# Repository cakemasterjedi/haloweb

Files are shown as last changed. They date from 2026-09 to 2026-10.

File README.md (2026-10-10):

# Digital BMW emblem (ESP32-S3 2.8" round display)

Board: [Waveshare ESP32-S3-LCD-2.8C](https://www.waveshare.com/wiki/ESP32-S3-LCD-2.8C).
The display is driven the same way as Waveshare's own demo: same ST7701 start-up
commands over hardware SPI, and ESP-IDF's RGB panel driver with the demo's pins,
timings and bounce buffers (Arduino core 3.x via pioarduino).

Firmware that turns the ESP32-S3 2.8" 480×480 round display board into a
digital roundel for the car. You control it from your phone's browser, so
there's no app to install.

## Install it (no coding needed)

Open the **[web installer](https://cakemasterjedi.github.io/haloweb/)** in Chrome or Edge on a
computer, plug the board in with a USB-C data cable and click **Install**. It always has the
newest build, plus the update file for installing updates from your phone later.

The installer is built and published automatically by
[`.github/workflows/web-installer.yml`](.github/workflows/web-installer.yml) on every push to
`main` that changes the firmware.

## What it can show

| Mode | What it looks like | Speed slider |
|---|---|---|
| **Roundel** | The classic badge: thin silver rims, glossy black ring with bold upright lettering, blue and white quarters. Colours and lettering are editable; presets Classic, Blackout, Motorsport, Carbon, Gold | – |
| **Spin** | Roundel with the quarters rotating | spin speed / direction |
| **Stripes** | M tri-colour stripes on carbon-fibre twill | 0 = static, otherwise scrolls |
| **Picture** | Photos, GIFs or videos from your phone (10 slots). Fill / Fit / Fit circle, zoom (pinch), drag, rotate | – |
| **Text** | Your own text, `\|` starts a new line (e.g. `M\|POWER`) | – |
| **M 50** | The "50 Years of BMW M" badge (the 1973 BMW Motorsport emblem): a small classic roundel on white enamel with light blue, dark blue and red half circles around it | – |
| **M 50 Spin** | M 50 with the quarters rotating | spin speed / direction |

All modes also have **brightness** and **rotation** (to level the emblem if it's
mounted at an angle). Settings are saved on the board.

- **Colours:** tapping any colour opens a colour wheel (works the same in
  Firefox and Chrome) with brightness and saturation sliders, hex and RGB
  entry, BMW paint colours and your recent colours. The emblem follows as you
  pick; Cancel puts the old colour back.

- **Auto-cycle** (Emblem tab): rotates through the designs you pick (modes and
  picture slots) every 5 s – 10 min. An animation finishes its loop before the
  next design comes on.
- **Smooth transitions:** designs crossfade into each other (Settings).
- **Animation speed:** 25–300 % for uploaded animations (Emblem tab, shown when
  an animation is selected).
- **Special dates** (Emblem tab): a design for certain days every year, e.g.
  1–26 Dec → your Christmas animation (up to 8 dates, presets for common
  holidays). On those days it replaces the normal design and auto-cycle.
- **Start-up** (Settings): the built-in animation (the ring sweeps in, the
  quarters spin into place, a glint crosses the badge), any picture or
  animation slot, or off. Then your selected design takes over.

## Power (the Power tab)

- **Normal mode:** optionally turns itself off after 5 min – 4 h, counted from
  power-on or your last change on the phone.
- **Car show mode:** stays on (for 1–24 h, or until the battery is low) with its
  own brightness.
- **Battery protection:** live voltage readout; turns off if the voltage stays
  below your cutoff for 30 s (so cranking dips don't trigger it). After a
  low-voltage shutdown it wakes every 10 minutes and comes back on once the
  battery is above the cutoff + 0.3 V.
- **Voltage source:**
  - *Board LiPo* – a battery on the board's battery connector (GPIO4).
  - *Car battery* – an **INA219** module on the board's I2C connector
    (SDA 15, SCL 7, 3.3 V, GND; VIN+ to the car battery +, VIN- can be left
    unconnected, and the module's GND to the car's ground). Every analog pin that
    works alongside Wi-Fi is taken by the display, so a 12 V battery can't be read
    directly.
  - Calibrate against a multimeter reading from the page.
- **Night dimming:** its own brightness between two times (default 19:00 –
  07:00), fading over. The board's clock chip keeps the time while it has
  power; it's set whenever you open the page, and from the internet when it's
  on your hotspot.
- **"Off" is deep sleep:** screen, backlight and Wi-Fi off. Wake it with the
  **BOOT** button or by cutting and restoring power. The board still draws a
  little current asleep (regulator, USB chip, LEDs), so for zero drain use an
  ignition-switched supply.

> **Auto-off and always-on fuses:** if the emblem runs from an always-on fuse, leave
> **Power → Turn off after** on **Never** unless you've fitted a kill switch. Once auto-off turns it
> off, it stays off until the BOOT button on the board is pressed (or a kill switch cuts and restores
> its power). Battery protection is
> separate: after a low-voltage shutdown it wakes by itself.

## G30 trunk emblem build

Want it in place of the trunk roundel on a G30 5 Series? The [`hardware`](hardware) folder has a slim
88 mm 3D-printed housing (10.3 mm off the paint; it locates on the factory peg holes and the wires go through one 16 mm hole),
an optional aluminium heat spreader with thermal pads, the wiring for the car battery and the INA219, and a step-by-step
[build guide](docs/G30_Emblem_Display_Build_Guide.pdf).

## Motion sensor (Settings tab)

The board has a motion sensor (QMI8658), used for:

- **Motion effects:** Spin, Stripes and animations speed up (up to 3×) when you
  accelerate or brake. Animations keep playing while driving either way.
- **Double-tap to change design:** tap the badge twice for the next design
  (the next auto-cycle design, or the next mode / picture). Ignored while
  driving. The page shows the last jolt so you can pick the sensitivity.
- **Welcome animation:** when the car has been still for 5 minutes, the next
  jolt (a door or the boot shutting) plays a welcome clip: the built-in
  animation or any picture/animation slot. Pick how big a jolt it needs.
- **Screen off when parked:** after the car has been still for a set time the
  screen goes dark; a jolt wakes it (with the welcome, if on), as does opening
  the page. The board stays on, so use the auto-off timer or battery
  protection for longer stops.
- **Level:** a one-time set-up on the bench (hold it upright → Step 1, turn it
  a quarter turn clockwise → Step 2) teaches it which way is up. Once fitted,
  park on level ground and tap *Level now*; it sets the rotation for you.
  Rotation now turns pictures and text as well as the roundel and stripes.

## Using it

1. Power the board. The first time, it makes its own Wi-Fi network,
   **`EMBLEM-xxxx`**, with a random temporary password, and shows both on its
   screen.
2. Join it from your phone. Most phones then open the control page on their
   own as a "sign in to network" page. If yours doesn't, browse to
   **http://192.168.4.1** (http://emblem.local also works on iPhones and computers, not Android).
3. On Android, when it warns that the network has no internet, choose
   **Stay connected**.
4. The first time, the page asks you to choose your own Wi-Fi password (and,
   if you like, a new name) before anything else; the emblem then restarts its
   Wi-Fi and you reconnect with the new password. Until then the emblem shows
   the temporary details and nothing else can be changed.
5. Add the page to your home screen so it works like an app.

Under **Settings** you can:

- rename the network or change its password;
- have the board also join another network, such as your phone's hotspot, so
  your phone keeps its internet. The page shows the address it gets there
  (it's also listed as "emblem" among the hotspot's devices). Use that
  address: `emblem.local` doesn't work in Android browsers;
- install firmware updates over Wi-Fi, so you don't need to reach the USB port
  once it's in the car.

## Android Auto (the car's screen)

`android/` is a small Android app that puts the emblem on the car's screen
through Android Auto. It shows up as a media app: two tabs, **Designs** and
**My pictures** (with thumbnails of your own pictures and animations), as
grids; "playing" a tile shows it on the emblem. The player's next button steps
to the next design and its two extra buttons make the emblem dimmer or
brighter. No sound is played, but while it's open Emblem is the car's "now
playing" app; switch back to your music app for its controls. It talks to the
emblem over Wi-Fi with the same requests as the web page, and finds it by
itself on the phone's hotspot (or at 192.168.4.1 on the emblem's Wi-Fi).

(Android Auto lists sideloaded media apps but not sideloaded template apps,
which is why it's built as a media app rather than with the Car App Library.)

It's installed outside the Play Store, so Android Auto has to be told to show
it, once:

1. Install `emblem-auto.apk` on the phone (allow installing from your browser
   or file manager when asked) and open it once; it should say "Emblem found".
2. Android Auto's settings (Settings → Connected devices → Connection
   preferences → Android Auto): scroll down, tap **Version** 10 times and
   allow developer settings.
3. ⋮ menu → **Developer settings** → turn on **Unknown sources**.
4. **Customise launcher**: make sure Emblem is ticked.

Build it with `cd android && ./gradlew assembleRelease` (needs the Android SDK;
the APK lands in `app/build/outputs/apk/release/`). It's signed with
`android/emblem.keystore`, so newer builds install over older ones. The design
icons in `res/drawable-nodpi` are drawn by the emblem's own renderer.

## Building & flashing

This is a [PlatformIO](https://platformio.org/) project. It works from VS Code
with the PlatformIO extension, or from the command line:

```bash
pio run -t upload        # build + flash over USB
pio device monitor       # serial log (shows the IP address)
```

The phone page lives in `web/index.html`. Every build embeds it into the
firmware automatically (`tools/embed_web.py` writes `include/web_ui.h`). After
the first USB flash, later updates can go over Wi-Fi: upload
`.pio/build/esp32-s3-display/firmware.bin` from the page.

### Working on it without the board

```bash
python3 tools/mock_server.py          # phone UI against a fake emblem: http://localhost:8000
g++ -O2 -std=c++17 -Isrc tools/host_preview.cpp src/renderer.cpp -o preview && ./preview .
                                      # renders every mode to .ppm images
```

## Pictures & animations

- **Photos** are stored at full quality (480×480).
- **GIFs** keep their own timing and work in any browser (Firefox, Chrome,
  Safari). Animated WebP needs a browser with ImageDecoder (Chrome, newer
  Firefox); otherwise its first frame is used.
- **Videos** (MP4, WebM, MOV): pick the frame rate (10–25 fps) and length
  (up to 60 s). Phone videos work straight from the camera in any browser,
  Firefox included: when the browser can't play HEVC (H.265) itself, the page
  decodes it with a WebAssembly decoder that the emblem serves (about 110 KB,
  `web/vendor/hevc`). HDR videos are tone-mapped to normal colours, and
  portrait videos come out upright. That decoding runs on the phone, so a long
  4K clip takes a while to prepare.
- **Size limits:** animations play straight from storage, so the limit is free
  space. Internal flash (~12 MB) allows up to 8 MB per animation; a micro SD
  card allows up to 32 MB. If a clip is too big, the page lowers the quality,
  then drops frames, until it fits. The line under the slots shows which
  storage is in use and how much is free.
- **Micro SD card:** optional. Insert it (FAT32) *before* powering up; the
  emblem then stores pictures in an `/emblem` folder on the card. Without a
  card it uses the internal flash. Pictures on one aren't copied to the other.
- **Screen goes dark while saving:** writing to the internal flash briefly
  stops the chip feeding the screen, which would show as torn blocks, so the
  backlight is off while a picture (or a firmware update) is being saved and
  fades back in with the new picture. With a micro SD card this isn't needed.

## Hardware notes

- **PSRAM:** the board has octal PSRAM (`memory_type = qio_opi`, as in
  Waveshare's demo). If the serial log ever shows `PSRAM ID read error`, that
  setting is wrong and the display can't start.
- **Serial log:** the USB-C port goes through a CH343 USB-serial chip, so the
  firmware logs to UART0 (`ARDUINO_USB_CDC_ON_BOOT=0`).
- **Hardware check:** `pio run -e diag -t upload` flashes a test that skips
  the display, starts an open `EMBLEM-TEST` network and reports chip, PSRAM
  and I2C details over serial and at http://192.168.4.1.
- **Pins** are in `include/display_config.h`.
- **Backlight / brightness** uses PWM on GPIO6. If your board doesn't have the
  backlight there, add `-DLCD_BL_PIN=-1` to `build_flags` to dim in software.
- **Panel timing** (*Settings* tab): 18 MHz pixel clock by default (Waveshare's
  ESP-IDF demo), plus 30 MHz and 12 MHz options. *Test colours* fills the screen
  red, green, blue, white.
- **Smooth output:** double-buffered (no tearing), and the RGB stream is
  re-synced after flash writes and once a second so the picture can't stay
  shifted if the S3 falls behind (a known ESP32-S3 RGB "drift").
- **Power in the car:** use a 12 V → 5 V USB buck converter on a switched
  (ignition) feed so it doesn't drain the battery. Fuse it.
- **Mounting:** the display isn't weatherproof. Behind a clear, sealed cover
  in the grille or boot, or inside the cabin (steering wheel, dash), is much
  safer than an exposed badge position. Direct sunlight will wash it out.
- **Road use:** rules on lit or animated badges vary by country and state.
  Check yours before driving with it lit.

## Project layout

```
src/main.cpp          Wi-Fi, web server, storage, display output
src/renderer.*        draws every mode into a frame buffer (portable C++)
src/label_font.h      bold letters for the ring (made by tools/gen_label_font.py)
src/stroke_font.h     vector font for text mode
src/settings.h        settings + defaults
src/motion.*          motion sensor (acceleration, double-tap, level)
src/rtc_clock.*       clock chip (night dimming)
web/index.html        phone control page
web/vendor/hevc/      HEVC video decoder for the page (hevc.js, MIT, with a tiles fix)
include/display_config.h  board pins / display init
tools/                web embedding, mock server, PC preview
```

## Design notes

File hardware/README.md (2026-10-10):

# G30 trunk emblem build (housing, wiring, install)

A slim, perfectly round 88 mm housing that sits over the 84 mm trunk badge holder on a G30 5 Series (made for a 2019 M550i) and holds a 2.8" round ESP32-S3 touchscreen. A centred 3" × 1.5 mm acrylic lens sits flush with the rim.

The display goes in **from the back**: the board drops into a wide pocket and the glass stops against a lip at the front. The top of the housing covers the screen's cable tab and ribbon, so there's no separate tab cap and from the front you see a clean circle. To fit the cable tab inside 88 mm, the screen sits 2.65 mm above the housing's centre under the centred lens.

A thin printed **back plate** (0.6 mm) drops into the base, rests on the board's brass studs and sits flush with the base. Its two short solid pegs locate in the factory badge holes, a shallow dome on its paint side fills the 0.86 mm dip in the badge seat, and the wires leave through its centre hole and **one 16 mm hole drilled at the badge centre**. One continuous 0.64 mm VHB ring inside the badge holder seals the housing base and plate edge to the paint. It stands **10.3 mm** off the paint, tape included.

**Start with the build guide:** [`../docs/G30_Emblem_Display_Build_Guide.pdf`](../docs/G30_Emblem_Display_Build_Guide.pdf). It covers parts, printing, the firmware install, wiring, fitting it to the car and the optional heat spreader.

## Files
| File | What it is |
|---|---|
| `print/Halo_88_HOUSING.3mf` | Housing, ready to print (back down) |
| `print/Halo_88_BACK_PLATE.3mf` | Back plate with centre hole and locating pegs (flat side down, pegs up) |
| `print/Halo_88_BACK_PLATE_SPREADER.3mf` | Same plate with a window and recess for the aluminium heat-spreader disc |
| `print/trunk_electronics_tray.3mf` | Clip-in tray for the 12 V → 5 V converter and INA219 (no drilling) |
| `stl/` | The same parts as STL files |
| `source/halo_housing.py` | Generator for the housing and both plates: every dimension is a value at the top |
| `source/trunk_electronics_tray.scad` | Editable OpenSCAD source for the tray |
| `VHB_tape_template.svg` | 1:1 cutting template for the tape ring (print at 100 %) |
| `Halo_Spreader_Disc_Template.svg` | 1:1 cutting template for the 50 mm aluminium disc |
| [`../docs/`](../docs) | Build guide (PDF), wiring diagram, short print and install notes, preview images |

## Key dimensions (defaults)
- Outside diameter **88 mm**, **10.3 mm** off the paint including the 0.64 mm VHB tape; 45° bevel on the bottom edge
- Display: Waveshare ESP32-S3-Touch-LCD-2.8C, 73.0 mm glass, 70.13 mm image, cable tab with ribbon loop at 6 o'clock; glass to brass studs 7.54 mm
- Clearances: 0.6 mm around the glass, 0.5 mm at the cable tab, board pocket 1.5 mm wider than the glass
- Lens: 3" (76.2 mm) × 1/16" (1.5 mm) clear acrylic disc (Enoin 3" × 0.060"), flush in a 1.5 mm pocket
- Back plate: 0.6 mm, 14 mm centre hole, pegs 4 mm × 6 mm, **56 mm** apart (same on every G30)
- Tape ring: 68 to 83.6 mm, inside the 84 mm badge holder

## Changing the design
```
pip install numpy scikit-image
python3 source/halo_housing.py
```
Edit the values in `P` at the top first: display size and clearances (`disp_clear`, `chin_hw`, `tab_clear`, `board_grow`), module depth, lens size and thickness (`lens_t`), outside size (`R`), peg length, the seat dip, and the spreader window and recess. The screen offset is worked out from the tab and ribbon size.

## Print
ASA (UV- and heat-resistant), 0.2 mm layers, 5 walls, 6 top / 5 bottom layers, flow +2–5 % so the walls are watertight. Outer wall about 40 mm/s, part cooling off for the first 3 layers and low after that, and dry filament: the 0.8 mm wall behind the cable ribbon at 6 o'clock shows fraying first. **No brim or supports needed.** Back plate: 3 walls and 100 % infill; let it cool on the bed so it stays flat. Do a test fit in PLA first.

## Heat spreader (optional)
Print `Halo_88_BACK_PLATE_SPREADER.3mf`, cut a 50 mm disc with a 16 mm hole from 0.016″ (0.4 mm) aluminium with the template, insulate its board side with Kapton tape, and put soft insulating thermal pads (3–6 W/mK, about 30 % thicker than the gap) on the hot parts on the back of the board. The disc sits flush in the plate's recess, the pads press on it through the window, and a 1.5 mm pad ring on its paint side bridges the dip in the badge seat, so the board's heat goes into the trunk lid. Everything stays inside the tape ring, so the seal is unchanged. See Appendix A of the guide.

## Hardware
- 3" × 1/16" (1.5 mm) acrylic disc and clear optical adhesive (LOCA). Don't use B-7000 or other solvent glues on acrylic; they craze it
- 0.64 mm 3M VHB tape (5925), cut into a ring with [`VHB_tape_template.svg`](VHB_tape_template.svg). Adhesion promoter recommended
- Black neutral-cure silicone (lens edge, glass edge, plate edge, wire hole, grommet)
- 28 AWG silicone wire, red + black (5 V + GND) and 30 AWG silicone wire × 4 (3.3 V + GND + SDA + SCL)
- 16 mm (5/8") step drill, 5/8" rubber grommet, touch-up paint
- Small silica gel pack
- 12 V → 5 V converter (YRDZXG 12/24 V → 5 V 5 A 25 W), INA219, **fuse tap kit with Mini and ATO taps** and 3 A fuses on an always-on circuit, ring terminal for chassis ground
- Optional: 12 V kill switch rated 5 A or more; aluminium sheet, thermal pads and Kapton tape for the heat spreader

## Wiring
Always-on fuse in the trunk fuse box → Mini or ATO fuse tap (to match the fuse) with a 3 A fuse → optional kill switch → INA219 sense terminals → converter. Converter ground goes to a chassis ground in the trunk lid. The converter's 5 V output and ground go to the board's 12-pin header: pin 2 is 5 V, pin 1 is GND. The INA219's 3.3 V, GND, SDA and SCL go to the board's I2C port. All six display wires pass through the 16 mm centre hole. See [`../docs/wiring_diagram.html`](../docs/wiring_diagram.html) (download it and open it in a browser).

## Notes
- **Firmware:** install it from the **[web installer](https://cakemasterjedi.github.io/haloweb/)** (Chrome or Edge, USB-C, one click). The first time it powers up it shows its own Wi-Fi name (`EMBLEM-xxxx`) and a temporary password on the screen; join it on your phone and choose your own password when the page asks.
- **Running with the car off:** the display runs from an always-on fuse. On the control page's Power tab, set the voltage source to Car battery (INA219) and turn on battery protection (cutoff about 12.2 V).
- **Auto-off: leave it on Never** (Power tab → Normal → Turn off after) unless you fitted a kill switch. Once auto-off turns the emblem off, it stays off until the BOOT button on the board is pressed, which you can't reach once it's sealed in, or until a kill switch cuts and restores its power. Battery protection is different: after a low-voltage shutdown it checks every 10 minutes and comes back on by itself once the battery recovers.
- **Heat guard:** the firmware dims the screen from about 70 °C on the chip and turns it off above 85 °C until it cools to 75 °C. The Power tab shows the temperature and the hottest it has been.
- Make sure the firmware and the phone control page work before sealing it up. The USB port isn't reachable once it's assembled; later updates go over Wi-Fi from the control page (Settings → Firmware).
- Rules on lit or animated displays facing backward vary by state and country. Check yours.
- Unofficial fan project, not affiliated with or endorsed by BMW.

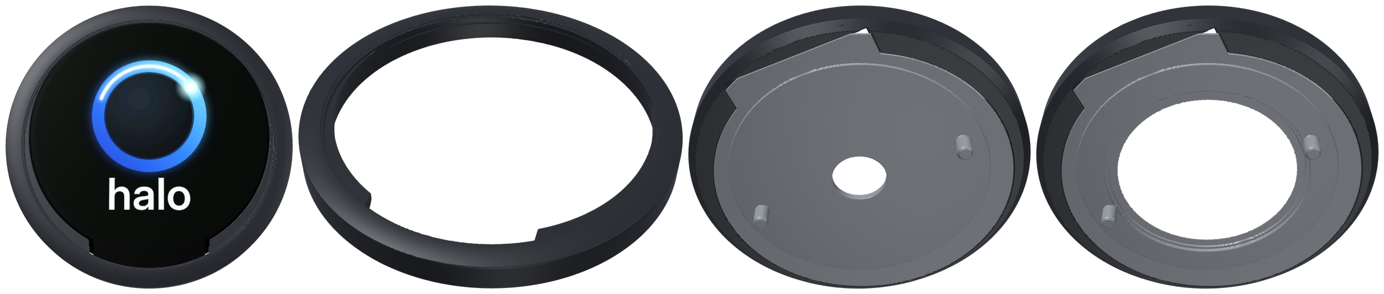
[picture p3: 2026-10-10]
docs/preview.png

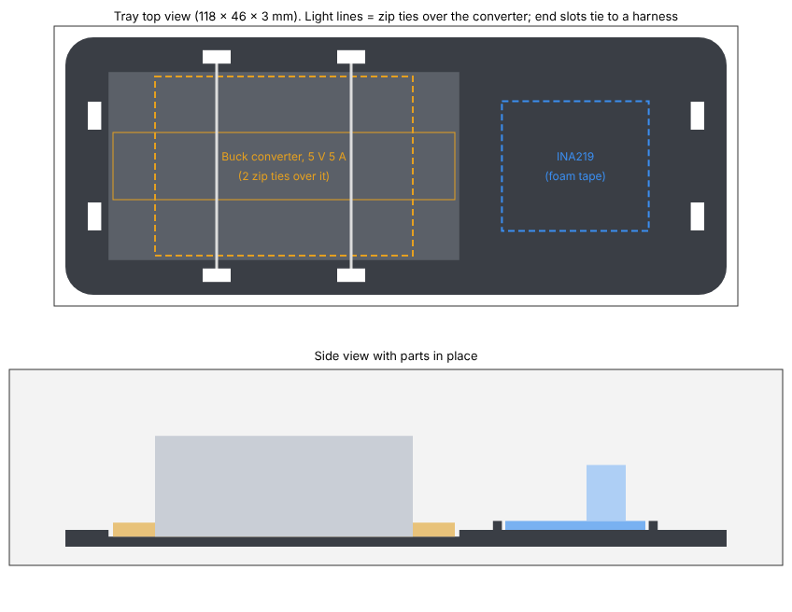
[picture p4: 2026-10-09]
docs/tray_preview.png

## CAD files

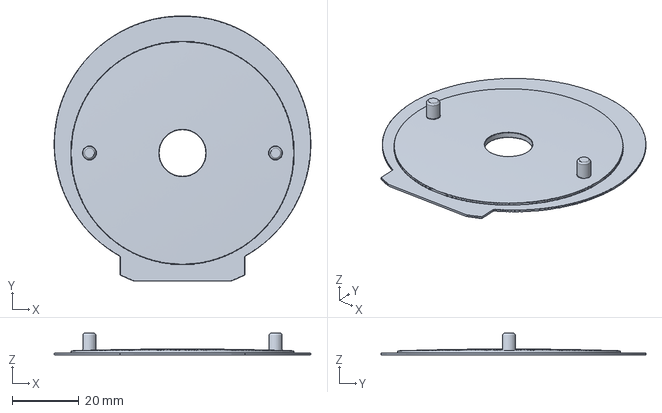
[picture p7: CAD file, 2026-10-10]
hardware/print/Halo_88_BACK_PLATE.3mf
77.2 x 79.7 x 6.60 mm

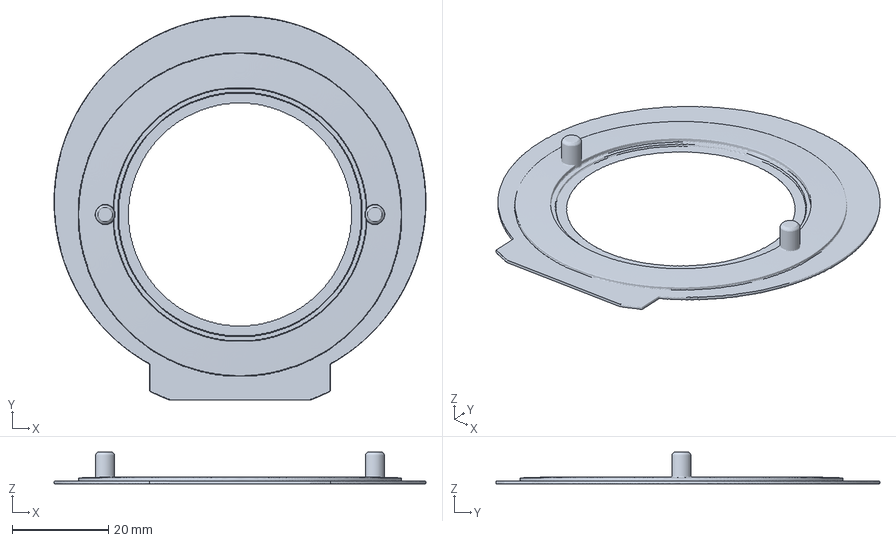
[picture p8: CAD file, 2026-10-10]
hardware/print/Halo_88_BACK_PLATE_SPREADER.3mf
77.2 x 79.7 x 6.60 mm

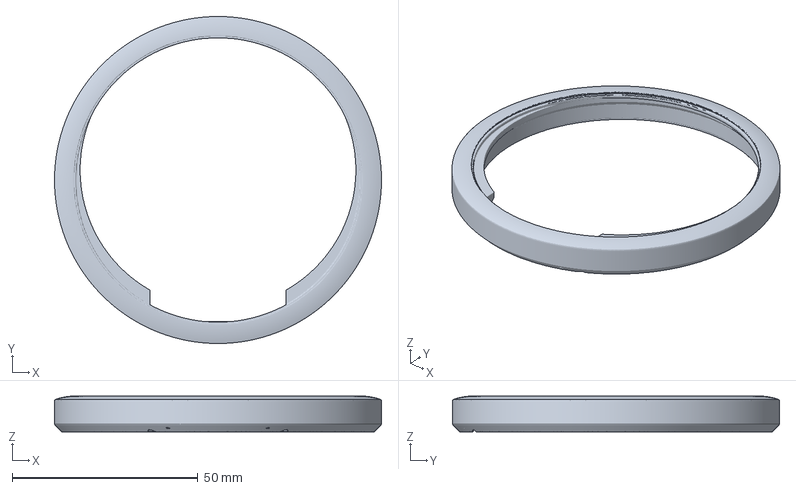
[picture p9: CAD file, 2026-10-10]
hardware/print/Halo_88_HOUSING.3mf
88.0 x 88.0 x 9.68 mm

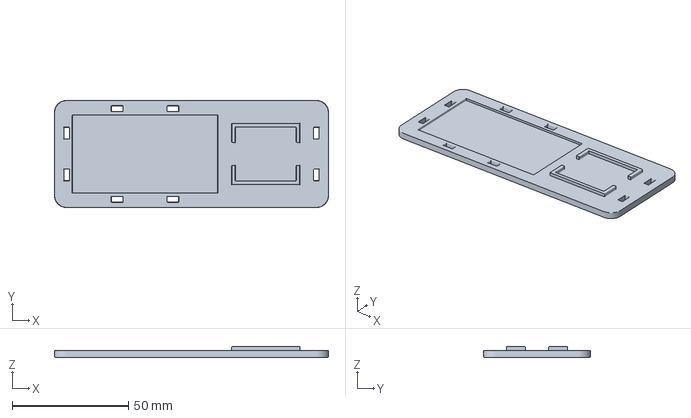
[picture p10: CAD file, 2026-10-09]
hardware/print/trunk_electronics_tray.3mf
118.0 x 46.0 x 4.60 mm

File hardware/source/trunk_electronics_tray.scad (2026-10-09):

// =====================================================================================
//  No-drill trunk-lid tray for the emblem display electronics
//  Holds: YRDZXG 12/24V->5V 5A 25W buck converter (body about 46 x 32 x 18 mm, 61 mm over the
//  mounting ears) + INA219 (GY-219, 25 x 22 mm)
//  Mounts with 3M VHB on the flat back, and/or zip ties around the existing trunk-lid wiring harness.
//  Units: mm. Print flat, back down, no supports.
// =====================================================================================

/* [Tray] */
plate_l = 118;
plate_w = 46;
plate_t = 3;
corner_r = 5;

/* [Buck converter] */
// Footprint of the converter including its mounting ears (length x width)
conv_l = 61;
conv_w = 32;
// Clearance around the converter footprint
conv_clear = 0.8;
// Depth of the locating pocket for the converter's base and ears
conv_pocket = 1.2;
// Centre of the converter along the tray
conv_x = -20;
// Distance between the two zip-tie straps over the converter
strap_spacing = 24;

/* [INA219 board] */
ina_l = 25;
ina_w = 22;
ina_clear = 0.6;
// Height of the low wall around the INA219
ina_wall_h = 1.6;
ina_wall_t = 1.6;
// Width of the wire gaps in the short walls
ina_gap = 10;
ina_x = 32;

/* [Zip ties] */
// Zip-tie width + clearance
tie_w = 5.0;
// Zip-tie thickness + clearance
tie_t = 2.4;
// Distance from tray end to the end slots (for strapping to a harness)
end_slot_inset = 4;
// Spacing of the two end slots across the tray
end_slot_spacing = 18;

/* [Hidden] */
$fn = 64;
CPL = conv_l + 2 * conv_clear;
CPW = conv_w + 2 * conv_clear;
IPL = ina_l + 2 * ina_clear;
IPW = ina_w + 2 * ina_clear;

module rounded_rect(l, w, r, h) {
    linear_extrude(height = h)
        offset(r = r) square([l - 2 * r, w - 2 * r], center = true);
}

module slot_x(cx, cy) { translate([cx - tie_w / 2, cy - tie_t / 2, -1]) cube([tie_w, tie_t, plate_t + 2]); }  // tie runs across Y
module slot_y(cx, cy) { translate([cx - tie_t / 2, cy - tie_w / 2, -1]) cube([tie_t, tie_w, plate_t + 2]); }  // tie runs across X

module tray() {
    difference() {
        union() {
            rounded_rect(plate_l, plate_w, corner_r, plate_t);
            // low wall around the INA219 with wire gaps in the short sides
            translate([ina_x, 0, plate_t]) difference() {
                translate([-(IPL / 2 + ina_wall_t), -(IPW / 2 + ina_wall_t), 0])
                    cube([IPL + 2 * ina_wall_t, IPW + 2 * ina_wall_t, ina_wall_h]);
                translate([-IPL / 2, -IPW / 2, -1]) cube([IPL, IPW, ina_wall_h + 2]);
                translate([-(IPL / 2 + ina_wall_t + 1), -ina_gap / 2, -1]) cube([IPL + 2 * ina_wall_t + 2, ina_gap, ina_wall_h + 2]);
            }
        }
        // locating pocket for the converter's base and ears
        translate([conv_x - CPL / 2, -CPW / 2, plate_t - conv_pocket]) cube([CPL, CPW, conv_pocket + 1]);
        // two straps over the converter body
        for (dx = [-strap_spacing / 2, strap_spacing / 2]) for (sy = [-1, 1])
            slot_x(conv_x + dx, sy * (CPW / 2 + tie_t / 2 + 1.5));
        // end slots: zip-tie the tray to a harness or bracket behind it
        for (sx = [-1, 1]) for (sy = [-1, 1])
            slot_y(sx * (plate_l / 2 - end_slot_inset - tie_t / 2), sy * end_slot_spacing / 2);
    }
}

tray();

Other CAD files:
hardware/stl/Halo_88_BACK_PLATE_SPREADER.stl

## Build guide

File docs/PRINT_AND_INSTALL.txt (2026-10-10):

G30 TRUNK EMBLEM DISPLAY — PRINT & INSTALL NOTES  (88 mm housing, display loads from the back, one 16 mm hole)
=========================================================================================
Parts
  Halo_88_HOUSING.3mf               print BACK-DOWN (as oriented)
  Halo_88_BACK_PLATE.3mf            print FLAT SIDE DOWN, pegs up (as oriented)
  Halo_88_BACK_PLATE_SPREADER.3mf   instead of the plain plate if you fit the aluminium heat spreader (guide Appendix A)
  Generator: hardware/source/halo_housing.py (python3 halo_housing.py; needs numpy + scikit-image)

Print settings (ASA, enclosed printer)
  0.2 mm layers, 5 walls, 6 top / 5 bottom layers, 40% gyroid infill,
  flow +2-5 % (thick, slightly over-filled walls are what make the print watertight)
  Clean walls: outer wall ~40 mm/s, inner walls first, no part cooling for 3 layers then 10-20 %, dry filament.
  NO BRIM, no supports: the bottom edge is a 45 deg bevel and the board-pocket roof is a 45 deg slope.
  Textured PEI or glue stick, bed 100-110 C, enclosure closed.
  Back plate: 3 walls, 100% infill, cool on the bed so it stays flat
  Test-fit in PLA first: display in from the back until the glass touches the front lip, plate flush with the base.

Factory-look finish (optional)
  Wet-sand 400 -> 800 -> 1500, plastic adhesion promoter, filler primer, gloss black, 2K clear.
  Keep paint out of the lens pocket and off the base where the tape goes.

Hardware
  3" x 1/16" (76.2 x 1.5 mm) acrylic disc (lens, flush in a 1.5 mm pocket) + clear LOCA  (not B-7000: it crazes acrylic)
  0.64 mm 3M VHB 5925 (one continuous ring, 68-83.6 mm, cut with VHB_tape_template.svg at 100 %),
    adhesion promoter, isopropyl alcohol
  Black neutral-cure silicone, silica gel pack, conformal coating (MG Chemicals 422C or 419D)
  28 AWG silicone wire red + black, 30 AWG silicone wire x4 (all six through the centre hole)
  16 mm (5/8") step drill, 5/8" rubber grommet, touch-up paint
  12 V -> 5 V converter (YRDZXG 12/24 V -> 5 V 5 A 25 W), INA219, fuse tap kit with MINI and ATO taps + 3 A fuses in both sizes, ring terminal
  Optional: 12 V kill switch, 5 A+ (inline rocker on a pigtail)
  Optional heat spreader: 0.016" (0.4 mm) aluminium sheet (50 mm disc, 16 mm hole; Halo_Spreader_Disc_Template_1to1.pdf),
    soft insulating thermal pads 0.5-1.5 mm (3-6 W/mK), Kapton tape, 1.5 mm pad ring for the paint side

Wiring
  ALWAYS-ON fuse -> Mini or ATO fuse tap to match it (3 A) -> [kill switch] -> INA219 VIN+ ; VIN- -> converter IN+ ; converter IN- -> chassis ground
  Converter OUT+ -> board 12-pin pin 2 (5 V);  OUT- -> pin 1 (GND)
  INA219 VCC/GND/SDA/SCL -> board I2C port 3V3 / GND / GPIO15 / GPIO7
  All six display wires go through the 16 mm centre hole. Never feed 12 V to the board. Don't ground through the trunk skin.

Assembly (display unit)
  1 Make the cables; plug into the 12-pin header + I2C port; route the wires flat to the middle of the board.
  2 Conformal-coat the back of the board and both plugged connectors (mask USB-C, BOOT/RESET, keep off the glass).
  3 Optional: thermal pads on the hot parts + aluminium disc in the SPREADER plate (guide Appendix A).
  4 Display in FROM THE BACK, tab at 6 o'clock, until the glass touches the front lip. Ribbon loop into its pocket.
    Don't force it: find what catches and trim.
  5 Wires through the plate's centre hole; plate into the base (pegs out). It rests on the brass studs, flush with the base.
  6 Silicone around the plate edge and around the wires in the centre hole. 24 h cure.
  7 Confirm the phone control page works.
  8 Silicone the glass edge from the front. Lens into the 1.5 mm pocket with a thin LOCA layer, flush. Seal the lens edge.
  9 After 24 h: water test. Test tape ring on a tile, water to 2 cm below the rim for 30 min, then a garden
    hose for 2 min. No fog, silica gel dry. Fit fresh tape for the car.

Install
  1 Remove the factory roundel; leave the two grommets in the peg holes (the plate's pegs locate in them). Check they sit flush.
  2 Drill 16 mm at the exact centre between the peg holes (check behind the panel first). Deburr, paint the edge, fit the grommet.
  3 Clean the paint with IPA, adhesion promoter. One continuous VHB ring on the base (covers the housing base and plate edge).
  4 Wires through the grommet (seal with silicone), pegs into the factory holes, cable tab at 6 o'clock, press 30 s.
  5 Join the wires to the tray inside the lid. Let cure 24 h before washing.

Washing: hand, rain, touchless/brush car washes fine. Pressure washer: 25 or 40 degree tip, 30 cm (1 ft)+
  away, keep it moving, not on the rim edge, never a 0 degree tip. Sealed to IP67 practice, not lab-certified.
Heat: the board's ESP32-S3R8 is rated to 65 C air and the LCD to 70 C (80 C storage). The firmware's heat
  guard dims the screen from 70 C (chip) and turns it off above 85 C until it cools to 75 C. The optional
  aluminium spreader + thermal pads move the board's heat into the trunk lid.

Firmware: install from https://cakemasterjedi.github.io/haloweb (Chrome/Edge, USB-C).
  Phone: first power-up shows its Wi-Fi (EMBLEM-xxxx) and a temporary password on the screen;
  join it and choose your own password when the page asks.
  Power tab: voltage source Car battery (INA219), battery protection on, cutoff ~12.2 V.
  Auto-off: leave on NEVER. Once it turns off it stays off until the BOOT button on the board is pressed
  (sealed inside the housing) or a kill switch cuts and restores its power.
Finding an always-on fuse: lock the car, wait ~20 min, test which fuses are still live.

Key dimensions: 88 mm OD (over the 84 mm badge holder), 10.3 mm off the paint including the 0.64 mm VHB.
  Screen 2.65 mm above centre under a centred 3" lens. Pegs 4 mm x 6 mm, 56 mm apart. Wire hole 16 mm at the centre.

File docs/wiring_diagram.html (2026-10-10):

# Emblem Display Wiring

Power and voltage sensing for the trunk-emblem screen: 12 V from an always-on fuse in the trunk fuse box (through an optional kill switch), through the INA219 and the 12 V → 5 V converter in the trunk lid, then up through one 16 mm hole drilled at the badge centre (in a grommet) to the board.

12 V passes through the INA219's sense terminals before the converter, so the board can read the car's voltage. All six display wires go up through the 16 mm centre hole.

12 V 5 V Ground 3.3 V SCL SDA

## Connection checklist

✓ | From | To | Wire
| Fuse tap output (3 A fuse) | Kill switch, if fitted | 12 V
| Kill switch (or fuse tap) | INA219 VIN+ | 12 V
| INA219 VIN− | Converter IN+ (red lead) | 12 V
| Converter IN− (black lead) | Chassis ground point in the trunk lid | Ground
| Converter OUT+ (yellow lead) | Board 12-pin header, pin 2 (5 V) | 5 V
| Converter OUT− (black lead) | Board 12-pin header, pin 1 (GND) | Ground
| INA219 VCC | Board I2C port 3V3 | 3.3 V
| INA219 GND | Board I2C port GND | Ground
| INA219 SCL | Board I2C port SCL (GPIO7) | SCL
| INA219 SDA | Board I2C port SDA (GPIO15) | SDA

## Before you power it up

Power the INA219 from the board's 3.3 V, never from the converter's 5 V. Its pull-ups would put 5 V on the ESP32's data pins. And never connect 12 V to the board's BAT connector.

## Notes

- Which circuit: to keep the display running with the car off, tap an always-on (constant, terminal 30) fuse in the trunk fuse box, on the right side behind the trim cover. Find one with a test light or multimeter: lock the car, wait about 20 minutes for it to go to sleep, and check which fuses are still live. Avoid airbag, fuel pump, DSC and engine-computer fuses. The firmware's battery saver turns the display off if the battery gets low.
- Kill switch (optional): for a car that sits for weeks, put a switch in the 12 V line right after the fuse tap so you can turn the display fully off. Use a 12 V switch rated 5 A or more: an inline rocker on a pigtail is easiest (no mounting), or a small sealed toggle tucked behind the trunk side trim near the fuse box.
- Fuse tap: the G30 fuse box has both Mini and ATO (standard-size) blade fuses. Check the size of the fuse you tap and use the matching add-a-circuit with a 3 A fuse of the same size (a kit with both is easiest). The original fuse goes in the lower slot and the new 3 A fuse in the upper one. Fit the tap in the direction that puts its lead on the load side.
- Chassis ground: use an existing body ground stud or bolt in the trunk lid, on bare metal. Don't ground through the painted skin.
- Cables: two 28 AWG silicone wires (5 V + GND; keep the run under 1 m) and four 30 AWG silicone wires (3.3 V, GND, SDA, SCL), all through the back plate's centre hole and the 16 mm grommet. Seal both around the wires with silicone.
- Shared ground: the converter's input and output grounds are common, so the INA219's GND (to the board's I2C port) shares the same ground as the 12 V side, which it needs to read voltage.
- Address: the INA219 is at I2C address 0x40, which doesn't clash with the board's touch, RTC, IMU or IO-expander chips.

## Reading the voltage (Arduino)

#include <Wire.h>
#include <Adafruit_INA219.h>

Adafruit_INA219 ina;               // default address 0x40

void setup() {
  Wire.begin(15, 7);               // board's I2C: SDA = GPIO15, SCL = GPIO7
  ina.begin(&Wire);
}

float carVolts() {                 // voltage at VIN+ (the 12 V feed)
  return ina.getBusVoltage_V() + ina.getShuntVoltage_mV() / 1000.0;
}

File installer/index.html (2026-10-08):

# Install the emblem firmware

For the Waveshare ESP32-S3 2.8C round display. Nothing to download or install on your computer: this page does it from the browser.

## 1. Install

1. Use Chrome or Edge on a computer (Windows, Mac, Linux or Chromebook). Phones, Safari and Firefox can't do this.
2. Plug the display into the computer with a USB-C data cable. Some cables only charge; if nothing shows up, try another one.
3. Click Install, pick the port that appeared (it usually has USB or CH343 in the name), click Connect, then Install.
4. Wait for Installation complete (about a minute). The display restarts with the emblem on it.

Install This browser can't install firmware. Open this page in Chrome or Edge on a computer. Open this page from its https address, not as a file on your computer.

Firmware build __VERSION__

No port in the list? Windows usually installs the USB driver by itself after a minute. If it doesn't, install the CH343 driver from wch-ic.com and try again. Still nothing: unplug, hold the board's BOOT button, plug back in, let go, and click Install.

## 2. Control it from your phone

1. Power the display. The first time, it makes its own Wi-Fi network (EMBLEM- and four characters) with a temporary password, and shows both on its screen.
2. Join it on your phone with that password. The control page opens by itself; if not, open http://192.168.4.1. On Android, choose Stay connected when it says there's no internet.
3. Choose your own Wi-Fi password (and a name if you like) when the page asks. The emblem restarts its Wi-Fi; rejoin with your new password, then pick a design and brightness.
4. Car battery reading: on the Power tab set the voltage source to Car battery (INA219), turn on battery protection and calibrate it with a multimeter reading.

Always-on fuse? Leave auto-off on Never. On the Power tab, keep Turn off after on Never unless you've fitted a kill switch. Once auto-off turns the emblem off, it stays off until the BOOT button on the board is pressed (or a kill switch cuts and restores its power). Battery protection is separate and turns it back on by itself once the battery recovers.

## 3. Updating later

Once it's in the car you don't need the USB port. Download the update file, join the emblem's Wi-Fi, and install it from the control page under Settings → Firmware.

Download update file

This always has the newest build. Use this file for phone updates; the Install button above is for the first install over USB.

Source code, 3D-print files and the build guide: github.com/cakemasterjedi/haloweb

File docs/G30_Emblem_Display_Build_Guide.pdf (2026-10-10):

B U I L D & I N STA L L G U I D E · B MW G 30 5 SERI ES

# Trunk Emblem Display

### A round 2.8″ ESP32 touchscreen in a 3D-printed 88 mm housing that sits over the trunk badge holder. It has an open back so it stands just 10.3 mm off the paint, locates on the factory peg holes, takes its wires through one 16 mm hole drilled at the badge centre, runs from an always-on 12 V fuse

with battery protection, and shows the classic roundel or your own designs, controlled from your phone.

Everything is at github.com/cakemasterjedi/haloweb
Install the firmware: cakemasterjedi.github.io/haloweb. Print files are in the hardware folder, and this guide and the wiring diagram are in docs. Green Code button → Download ZIP gets it all at once.

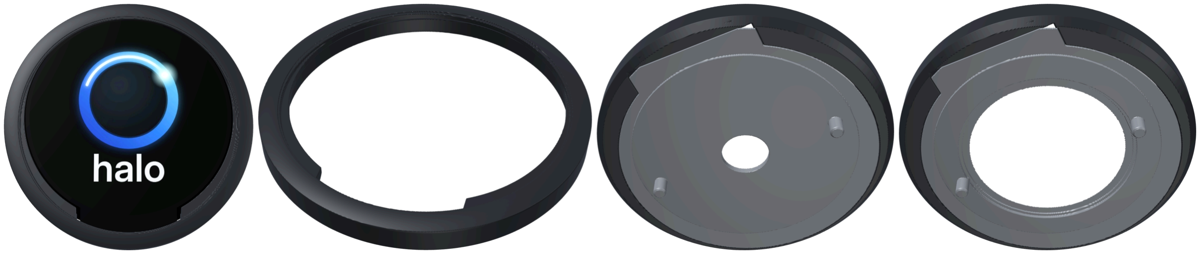
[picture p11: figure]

88 mm

outside diameter (fits over the 84 mm badge holder)

10.3 mm

off the paint, including the tape

16 mm

one hole drilled at the badge centre for the wires

G30 Trunk Emblem Display · 1 / 17

# Contents

1 Before you start
2 Parts and tools
3 Printing
4 Firmware
5 Wiring overview
6 Build the display unit

7 Build the trunk-lid tray 8 Install on the car
9 Test and calibrate
10 Troubleshooting
A Heat spreader and thermal pads

# 1 Before you start

The build has two units. The display unit replaces the badge: a printed 88 mm housing holding the Waveshare board, with a clear 3″ acrylic lens flush with the rim. The display goes in from the back: the board drops into a wide pocket and the glass stops against a lip at the front, and the top of the housing covers the screen's cable tab, so from the front you see a clean circle. A thin printed back plate closes the back. It drops into the base, rests on the board's brass studs and sits flush with the base, and its two short solid pegs locate in the factory badge holes. The wires leave through a hole in the middle of the plate and one 16 mm hole drilled at the badge centre. The trunk-lid tray sits behind the lid's inner trim and holds the 12 V → 5 V converter and the INA219 voltage sensor.

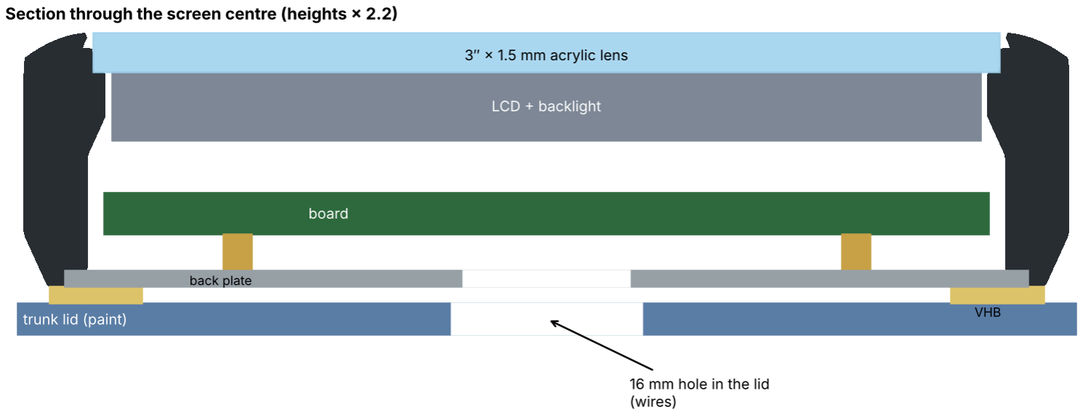
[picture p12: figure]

How the parts stack (heights exaggerated). The glass sits against the front lip, the board's brass studs rest on the 0.6 mm back plate, the housing base and plate edge sit on a 0.64 mm VHB ring inside the badge holder, and the 1.5 mm lens sits on the glass, flush with the rim. The screen sits 2.65 mm above the housing's centre under a centred lens; that is what lets its cable tab fit inside 88 mm.

Read these first
Battery: disconnect the 12 V battery (in the trunk on the G30) before any wiring, and tap an always-on circuit only with the firmware's battery protection turned on (section 4). Fit the kill switch if the car sits for weeks.
Legal: rules on lit or animated displays facing backward vary by state and country. Check yours; a dim or static image is the safe choice while driving.
Sealing: the display is sealed shut with silicone. Install the firmware and check the phone control page works before step 6.10 (bonding the lens), because the USB port can't be reached afterwards. Drilling: this version needs one 16 mm hole in the trunk lid at the badge centre (section 8). Check behind the panel before you drill.
Heat: print the final parts in ASA. PLA and PETG soften on a sunny trunk lid. For extra cooling, see Appendix A.

Unofficial fan project, not affiliated with or endorsed by BMW. Work at your own risk.

# 2 Parts and tools

PART | QTY | NOTES
Waveshare ESP32-S3-Touch-LCD- 2.8C | 1 | 73 mm round glass, 480×480. Comes with 12-pin and 4-pin SH1.0 cables.
3″ × 1/16″ clear acrylic disc | 1 | Enoin 3″ × 0.060″ (76.2 × 1.5 mm). The lens; it sits flush in a 1.5 mm pocket.
INA219 module (GY-219) | 1 | 25 × 22 mm. Reads the car's voltage over I2C.
YRDZXG 12/24 V → 5 V 5 A 25 W buck converter | 1 | Sealed. Body about 46 × 32 × 18 mm, 61 mm over the mounting ears. Red/black in, yellow/black out.
28 AWG silicone wire, red + black | ~1 m each | 5 V and ground. All six display wires leave through the centre hole.
30 AWG silicone wire, 3 colors | ~1 m each | 3.3 V, GND, SDA, SCL (4 wires).
20 AWG automotive wire, red + black | ~3 m each | 12 V feed from the fuse box to the trunk lid.
Fuse tap kit (Mini and ATO) + 3 A fuses | 1 | The G30 fuse box has both Mini and ATO (standard-size) blade fuses. Get a kit with both tap sizes and 3 A fuses in both sizes; you use the one that matches the fuse you tap.
12 V kill switch, 5 A or more (optional) | 1 | Inline rocker on a pigtail, or a small sealed toggle. Turns the display fully off for storage.
16 mm (5/8″) step drill + 5/8″ rubber grommet | 1 | The wire hole at the badge centre. Plus touch-up paint for the bare edge.
Ring terminal (M6 / ¼″) | 1 | Chassis ground.
Solder-seal heat-shrink connectors | ~10 | Waterproof wire joins.
LOCA UV-cure optical glue | 1 | Bonds the lens to the screen glass. Not B-7000 or super glue: they craze acrylic.
Permatex Ultra Black (82180) | 1 | Sensor-safe, neutral-cure silicone for all seals.
3M VHB 5925 (0.64 mm), black, 1″ | 1 roll | Cut into a ring with the template in section 8. It sits inside the 84 mm badge holder under the housing base and plate edge.
3M adhesion promoter, isopropyl alcohol | — | Surface prep for the VHB.
Mini silica gel pack | 1 | Taped to the back of the board.

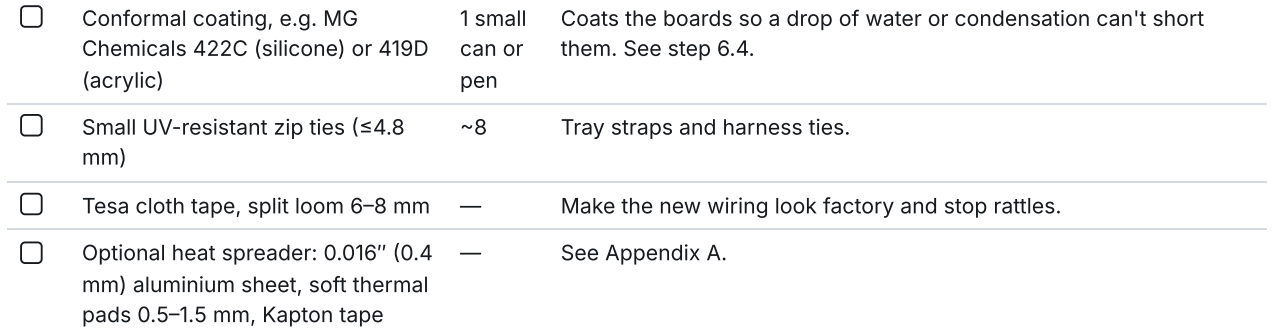
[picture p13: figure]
Conformal coating, e.g. MG Chemicals 422C (silicone) or 419D (acrylic); 1 small can or pen; them. See step 6.4.; Small UV-resistant zip ties (≤4.8 mm); Tray straps and harness ties.; Optional heat spreader: 0.016″ (0.4 mm) aluminium sheet, soft thermal pads 0.5–1.5 mm, Kapton tape; See Appendix A.

| | Coats the boards so a drop of water or condensation can't short
Tesa cloth tape, split loom 6–8 mm | — | Make the new wiring look factory and stop rattles.

ASA filament (black) + PLA for test
fit
— | Polymaker, Bambu or eSun ASA.

Tools: 3D printer (enclosed for ASA), soldering iron, wire strippers for 20–30 AWG, heat gun, multimeter, trim removal tools, painter's tape, UV flashlight (for LOCA), masking tape, USB-C cable and a computer with Arduino IDE.

# 3 Printing

FILE | ORIENTATION | PURPOSE
Halo_88_HOUSING.3mf | Back down (as
supplied)

The housing. The display goes in from the back.

Halo_88_BACK_PLATE.3mf | Flat, pegs up (as supplied) | 0.6 mm plate that closes the back: centre hole for the wires, two 6 mm locating pegs, shallow dome under the paint side
Halo_88_BACK_PLATE_SPREADER.3mf | Flat, pegs up | Instead of the plain plate, if you fit the aluminium heat spreader (Appendix A)
trunk_electronics_tray.3mf | Flat, back down | Holds the converter and INA219 in the trunk lid

Settings (ASA)

0.2 mm layers, 5 walls, 6 top / 5 bottom layers, 40 % gyroid infill, flow about 2–5 % above your normal setting. Thick, slightly over-filled walls are what make an FDM print watertight; with the usual 2–3 walls, water can seep through the layer lines.
Clean walls: outer wall about 40 mm/s, inner walls first, part cooling off for the first 3 layers and low (10–20 %) after that. If a few layers look frayed or stringy, dry the filament (ASA picks up moisture) and slow the outer wall down; the housing's thin wall at 6 o'clock (behind the cable ribbon, 0.8 mm) is the part that shows it first.
No brim or supports needed. The housing's bottom edge is a 45° bevel and the board-pocket roof is a 45° slope, so nothing overhangs. Use a clean textured PEI or glue-stick bed at 100–110 °C with the enclosure closed.
Back plate: 0.2 mm layers, 3 walls, 100 % infill so the pegs are solid. Let it cool on the bed so it stays flat.

Test fit in PLA first

Adjusting the fit: every dimension is a value in hardware/source/halo_housing.py. Change it and run python3 halo_housing.py to write new STL and 3MF files.

Make a jig: drill two 5 mm holes 56 mm apart and a 16 mm hole midway between them through a flat scrap board. It stands in for the trunk lid during the test fit and assembly.

1

Push the display into the housing from the back, cable tab at 6 o'clock, until the glass stops against the front lip. It should go in by hand without forcing; the board sits in the wide pocket at the back, and the ribbon loop folds into the pocket below the tab.

2

Drop the back plate in, pegs out. It should rest on the board's brass studs and sit flush with the base. If it stands proud, the display isn't fully forward; find what's catching before going further.

3

4 Set the acrylic disc in the front pocket. It should sit flush with the rim. Stand the unit on the jig with the pegs in the holes. The base should sit flat; hold it against the trunk lid's badge holder to check the fit and curve.

5

Factory-gloss finish (optional): wet-sand 400 → 800 → 1500, adhesion promoter, filler primer, gloss black, 2K clear. Keep paint out of the lens pocket and off the base where the tape goes.

# 4 Firmware

No coding or software needed: it installs from a web page in about a minute. Do this on the bench, before the board goes into the housing.

Install it (once)

No port in the list? Install the CH343 USB driver from wch-ic.com, or unplug, hold BOOT, plug back in, let go and try again.

Control it from your phone

Set up the battery protection

On the Power tab, under Battery protection:

SETTING | WHAT TO CHOOSE
Voltage source | Car battery (INA219). The live voltage appears once the INA219 is wired (section 5).
Battery protection | On, cutoff about 12.2 V. If the voltage stays below it for 30 seconds the display turns off. It checks every 10 minutes and comes back on at 0.3 V above the cutoff (engine running or charger on).
Calibrate | Type in what a multimeter reads across the battery (section 9).
Power mode → Turn off after | Leave it on Never unless you fitted a kill switch: once off, it stays off until the BOOT button on the board is pressed (sealed inside) or the kill switch cycles its power. Car show: Until the battery is low.

Updating later: download the update file from cakemasterjedi.github.io/haloweb on your phone, join the emblem's Wi-Fi, and install it under Settings → Firmware.

On a computer (Windows, Mac, Linux or Chromebook), open Chrome or Edge. Safari, Firefox and phones can't do this.

1

2 Go to cakemasterjedi.github.io/haloweb. Plug the display into the computer with a USB-C data cable. Some cheap cables only charge; if nothing happens, try another cable.

3

Click Install. A box pops up with a list of ports: pick the one that appeared when you plugged in (it usually has USB or CH343 in the name), click Connect, then Install.

4

5 | Wait for Installation complete (about a minute). The display restarts with the emblem on it.
Power the display. The first time, it makes its own Wi-Fi network (EMBLEM- | and four characters)
with a temporary password, and shows both on its screen.

1

Join it on your phone with that password. The control page opens by itself; if not, open the browser and go to http://192.168.4.1. On Android, tap Stay connected when it says the network has no internet.

2

It asks you to choose your own Wi-Fi password (and a name if you like), then restarts its Wi-Fi. Rejoin with your new password (write it down) and pick a design and brightness.

3

# 5 Wiring overview

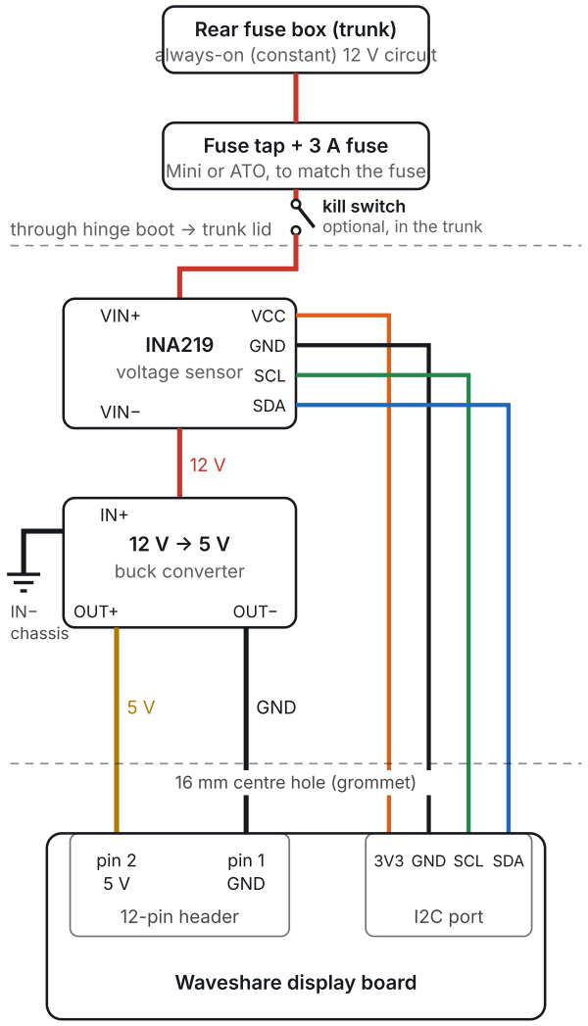
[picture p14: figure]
Rear fuse box (trunk) always-on (constant) 12 V circuit; Fuse tap + 3 A fuse Mini or ATO, to match the fuse; through hinge boot → trunk lid; kill switch optional, in the trunk; INA219 voltage sensor; VIN+; VIN−; VCC; GND; SCL; SDA; 12 V → 5 V buck converter; chassis; 16 mm centre hole (grommet); Waveshare display board; 12-pin header; pin 2 5 V; pin 1 GND; I2C port; 3V3 GND SCL SDA

IN− | OUT+ | OUT−

12 V passes through the INA219 before the converter. All six display wires go through the 16 mm centre hole.

FROM | TO

Fuse tap (3 A) → kill
switch, if fitted

INA219 VIN+

INA219 VIN− | Converter IN+ (red)
Converter IN− | (black) | Chassis ground stud
Converter OUT+ (yellow) | 12-pin header pin 2
(5 V)
Converter OUT− | (black) | 12-pin header pin 1
(GND)
INA219 VCC | I2C port 3V3
INA219 GND | I2C port GND
INA219 SCL | I2C port SCL (GPIO7)
INA219 SDA | I2C port SDA
(GPIO15)

Never
power the INA219 from the converter's 5 V (it would put 5 V on the ESP32's data pins), and never connect 12 V to the board's BAT connector.

Follow the pin labels printed on the board, not the wire colors of the supplied plug cables.

# 6 Build the display unit

How it's sealed

Every way in is closed: the lens is bonded to the glass with LOCA and its edge is sealed with silicone; the glass edge is sealed from the front; the back plate's edge and the wires in its centre hole are silicone; on the car, a continuous tape ring seals the housing base and plate edge to the paint, and the 16 mm hole has

Make the cables. Solder 28 AWG red and black to the 12-pin plug cable's pin 2 (5 V) and pin 1 (GND). Solder four 30 AWG wires to the 4-pin plug cable's 3V3, GND, SDA and SCL. Leave about 1 m on each, insulate every joint with heat shrink, and label the far ends.

Plug in. Plug the wires into the 12-pin header and the I2C port. Route them flat across the back of the board to the middle, staying clear of the brass studs, and twist them loosely into one bundle there.

Conformal-coat the board. With both plugs pushed fully home, mask the USB-C port and the BOOT and RESET buttons with tape and keep the coating off the front glass. Brush or spray a thin coat over the back of the board, the two connectors and the first centimetre of the wires. Let it dry as the can says and peel the masking.

Optional heat spreader: if you're fitting the aluminium disc and thermal pads, do it now, following Appendix A, and use the SPREADER back plate.

Fit the display from the back. Hold the housing face down on a soft cloth. Lower the display in, glass first and cable tab at 6 o'clock, and push it gently forward until the glass stops against the front lip all round. Fold the ribbon loop into the pocket below the tab. Don't force it: if it catches, find where and trim, rather than pressing on the glass.

Fit the back plate. Feed the wire bundle through the plate's centre hole from the board side, then drop the plate into the base, pegs out. It rests on the brass studs, flush with the base. Tape a mini silica gel pack to the back of the board first if there's room beside the studs.

Seal the back. Run a thin bead of black silicone around the plate's edge where it meets the housing, and fill the centre hole around the wires. Let it cure for 24 h.

Final firmware check. Power the board through the new wires (5 V supply or the converter) and confirm the screen, the voltage reading and the phone control page all work.

Seal the glass edge. From the front, run a thin bead of black silicone into the gap between the glass and the housing at the bottom of the lens pocket and let it cure.

Bond the lens. Clean the glass and the disc with isopropyl alcohol. Put a small pool of LOCA in the middle of the glass, lower the disc into the pocket from one edge so the glue spreads thin without bubbles, and press gently until it is flush with the rim. Wipe off the excess, then cure with UV light for the time given on the bottle.

Seal the lens edge with a fine bead of silicone in the 0.15 mm gap and let it cure.

Water test before it goes on the car (after 24 h of curing). Fit a test ring of tape on the base, stick the unit face up on a smooth tile and fill a bowl around it to 2 cm below the top of the rim for 30 minutes, then spray it with a garden hose for 2 minutes from all sides. Power it up and check: no fog under the lens, silica gel still dry. Peel the test tape and fit fresh tape for the car.

a grommet sealed with silicone; the board is conformal-coated with a silica gel pack inside for any trapped moisture.

Washing
Hand washing, rain and touchless or brush car washes are fine. With a pressure washer, use a 25° or 40° (green or white) tip, stay at least 30 cm (1 ft) away and keep the jet moving; don't hold it on the rim's edge, and never use a 0° (red) tip. Wait 24 h after fitting before the first wash.

About ratings: this build follows the sealing practice used for IP67 (immersion) and pressure-washer-proof parts, and the water test above checks your unit. It isn't certified: an official IP67 or IPX9K (high-pressure, hot-water jet) rating needs testing by a lab.

Don't use B-7000 on the lens
Its solvents can craze acrylic and fog the inside of the sealed housing.

# 7 Build the trunk-lid tray

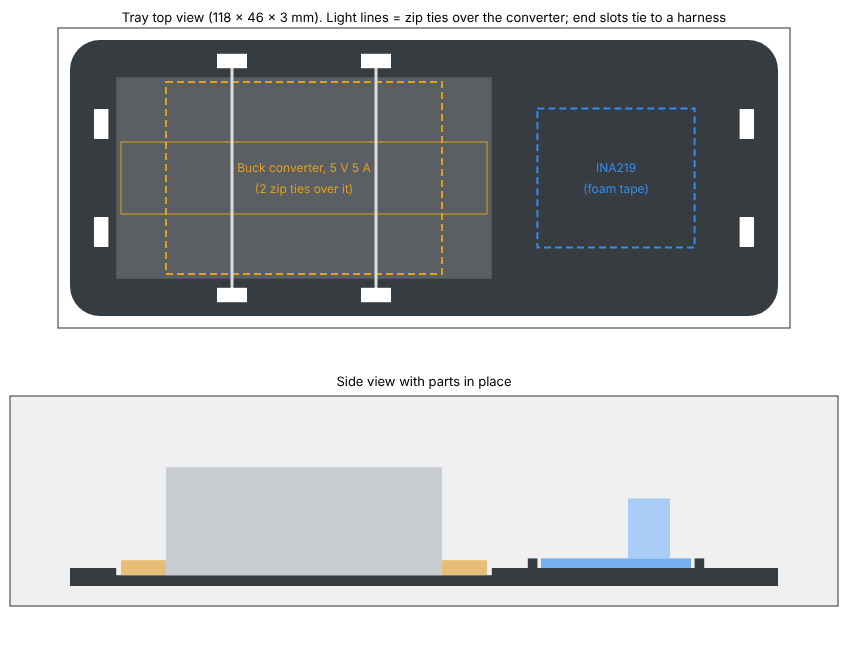
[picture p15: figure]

Converter strapped down with two zip ties; INA219 in its pocket on foam tape; end slots tie the tray to the trunk-lid harness.

Sit the converter's base and mounting ears in the pocket and strap it down with two zip ties through the slots beside it.

1

2 | Solder wires to the INA219 with the pins or wires facing up, then stick it in its pocket with foam tape.
Wire the 12 V path: incoming 12 V to VIN+, VIN− | to the converter's red input lead, converter's black
input lead to a ring terminal for ground. Use solder-seal connectors and heat shrink everywhere.

3

Join the converter's yellow and black output leads to the display's power pair, and the INA219's VCC, GND, SDA and SCL to the display's sensor wires. Each wire goes to its match: the INA219's GND to the sensor GND wire.

4

# 8 Install on the car

Remove the badge and prepare the paint

Run the 12 V feed

Mount the tray and the display

Open the trunk and remove the trunk lid's inner trim panel (it clips off) to reach the back of the badge and the lid harness.

1

Release the badge's pegs from inside if you can reach them, or pry the badge off from outside with a plastic tool. Leave the two grommets in the holes; the plate's pegs locate in them.

2

Check the grommets sit flush with the paint. If their heads stand proud, the plate will rock; trim them flush.

3

Drill the wire hole. Check behind the panel first for braces, wiring, the camera and the latch. Mark the exact centre between the two peg holes (28 mm from each), centre-punch it through a piece of painter's tape and drill 16 mm (5/8″) with a step drill. Deburr, vacuum the chips, paint the bare edge with touch-up paint and let it dry, then fit the 5/8″ grommet.

4

5 Clean the area with isopropyl alcohol, then wipe adhesion promoter where the tape ring will sit.

Find an always-on fuse in the trunk fuse box (right side, behind the trim cover). Lock the car and wait about 20 minutes for it to go to sleep. Clip a test light or the multimeter's black lead to a bare metal bolt, then touch the two little metal test points on top of each fuse. A fuse that still lights up (or reads about 12 V) on one side is always on.

1

Good ones to test first are the 12 V socket fuses (shown as "cigarette lighter / 12 V socket" on the fuse chart) and slots for features your car doesn't have. Never tap anything labelled DME, IVM, airbag, seatbelt, fuel pump, steering column or DSC.

2

Pull the fuse you chose and check its size: Mini (small) or ATO (standard, larger). Use the matching fuse tap and a 3 A fuse of the same size. Disconnect the battery. Fit the fuse tap with the original fuse in the lower slot and a 3 A fuse in the upper slot, turned so the new lead is on the load side.

3

Optional kill switch: splice it into the red lead right after the fuse tap and leave it where you can reach it, behind the trunk side trim flap near the fuse box. An inline rocker switch on a pigtail needs no mounting.

4

5 | Ring-terminal the ground to a factory ground stud on bare metal.
| Run the red 20 AWG lead along the factory harness to the trunk hinge and through the rubber boot into the lid, inside split loom, wrapped in Tesa tape. Keep it clear of the hinge, latch and any sharp edges.
6

Zip-tie the tray to the harness inside the lid (or VHB it to a clean inner panel), somewhere you can reach later. Connect the 12 V feed to the INA219's VIN+.

1

Cut the tape. Print the template below at 100 % scale (check the 50 mm line), lay the 0.64 mm VHB over it and cut one continuous ring. With 1″ tape, cut the four quarters, butt them tight and seal each joint with a dab of silicone.

2

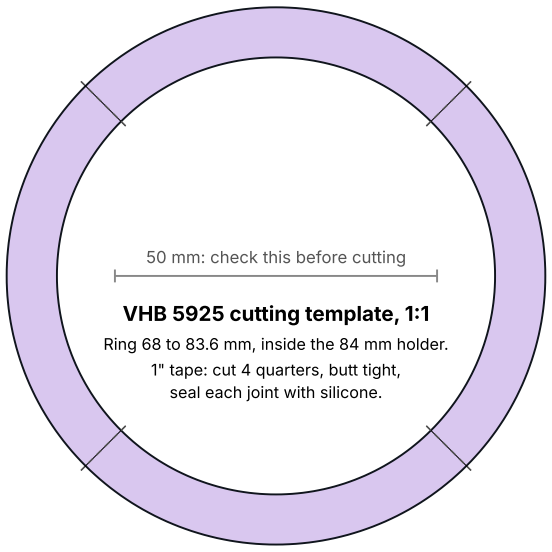
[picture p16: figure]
50 mm: check this before cutting; VHB 5925 cutting template, 11; 1" tape: cut 4 quarters, butt tight, seal each joint with silicone.

Ring 68 to 83.6 mm, inside the 84 mm holder.

VHB cutting template, 1:1. Print at 100 % (no "fit to page") and check that the line measures 50 mm. Also in the hardware folder as VHB_tape_template.svg.

3 | Stick the ring on the base so it covers the housing base and the edge of the back plate all round.
| Feed the wires through the grommet into the lid and seal the grommet around them with silicone. Peel the liner, line the pegs up with the factory holes (cable tab at 6 o'clock), set the housing into the badge holder and press it firmly all round for 30 seconds.
4
5 | From inside, join the wires to the tray as in step 7.4.
| Secure the loose wiring inside the lid with tape and zip ties, then refit the trim panel. Leave the car for 24 h before washing so the tape reaches full strength.
6

# 9 Test and calibrate

READING | WHAT IT MEANS
13.2 V and up | Engine running, alternator charging
12.4–12.8 V | Healthy battery at rest
12.0–12.4 V | Partly discharged
Under 12.0 V | Low; under 11.8 V for a minute triggers the optional backlight-off action

# 10 Troubleshooting

PROBLEM | CHECK
Display doesn't turn on | Fuse tap direction and 3 A fuse; 5 V at the converter output; pin 1 / pin 2 on the 12-pin header the right way round.
Voltage shows "No sensor" | INA219 VCC on 3.3 V (not 5 V); SDA/SCL not swapped; plugged into the I2C port, not the UART port.
Fog inside the lens | A seal is leaking or the housing was closed on a humid day. Replace the silica gel and reseal the glass edge. Assemble on a dry day.
Screen goes dark on a hot day, comes back later | That's the heat guard: it dims the screen from about 70 °C on the chip and turns it off above 85 °C until it cools to 75 °C. The Power tab shows the chip temperature and the hottest it has been. The ESP32-S3R8 on this board is rated to 65 °C air temperature and the LCD to 70 °C (80 °C when off).
Display goes dark when the car is off | The tapped fuse is switched, not always-on: pick another (section 8). Or the battery is under the cutoff; charge it. Or Normal mode auto-off is on: turn it off.
Battery runs down while parked | Raise the battery protection cutoff, or use the kill switch when the car will sit. Asleep, the display still draws a little.
1 | Reconnect the battery and wake the car. The display should boot within a few seconds.
| With the engine off, measure the battery with a multimeter. Join the emblem's Wi-Fi on your phone, open the Power tab, type the reading into Calibrate and tap Calibrate. The page and the screen now match the meter.
2
3 | Start the engine: the reading should rise to about 13.6–14.6 V and show "Charging".
| Lock the car and leave it. The display should stay on. If you want to test the battery protection, raise the cutoff above the battery voltage for a moment: after 30 seconds the display turns off, and it comes back within 10 minutes of starting the engine. Set the cutoff back afterwards.
4

5 If you fitted the kill switch, check it turns the display fully off.

Can't find the emblem's Wi-Fi | The display may be off (battery protection or auto-off). Turn it off and on with the kill switch or fuse. Look for the name you chose at setup (or EMBLEM- xxxx on a new display).
Web installer finds no port | Use Chrome or Edge on a computer and a USB-C data cable. Hold BOOT while plugging in, then try again.
Display won't go fully in, or the back plate stands proud | Something on the board or the cable tab is catching. Find the spot, trim it, or raise disp_clear, chin_hw or board_grow in halo_housing.py and reprint. The plate should sit flush with the base when the glass touches the front lip.
Lens sits low or proud | Lenses vary in thickness. Set lens_t in halo_housing.py to your disc's measured thickness and reprint.

# A Heat spreader and thermal pads (optional)

In full sun a black trunk lid gets very hot, and the board adds about 1 W of its own. This option moves that heat into the trunk lid instead of letting it build up inside the housing. It keeps the same height and the same tape-ring seal, because everything sits inside the ring.

Print Halo_88_BACK_PLATE_SPREADER.3mf instead of the plain plate. It has a 46 mm window and a 50.6 mm, 0.4 mm-deep recess on the paint side.
Cut the disc: print Halo_Spreader_Disc_Template_1to1.pdf at 100 %, tape it to 0.016″ (0.4 mm) aluminium sheet, cut the 50 mm disc with tin snips and step-drill the 16 mm centre hole so the wires still pass. File the edges smooth.
Insulate it: cover the disc's board side with Kapton tape, leaving bare spots only where pads sit, so nothing on the board can short to the metal.
Pads: with the display and plate dry-fitted, measure from the disc to the hot parts on the back of the board (ESP32 module, regulators, backlight driver). Use soft, electrically insulating gap pads (3–6 W/mK) about 30 % thicker than the gap so they compress lightly. Stick them on the hot parts.
Fit: glue the disc into the recess with a few dots of silicone at its edge, flush with the plate, then fit the plate as in step 6.6. The pads press lightly on the disc through the window.
On the car: the badge seat dips about 0.86 mm at the centre, so there's a 1–1.5 mm gap under the disc. Fill it with a 1.5 mm soft thermal pad ring (50 mm across, 16 mm hole) on the disc's paint side so the disc touches the paint through the pad.

What to expect: my estimate is a few degrees to about 10 °C cooler in full sun; it can't make the display cooler than the lid itself. The Power tab's hottest-temperature record shows the real difference.

Other ways to keep it cooler

Turn brightness down in summer; the backlight is most of the heat.
Use darker designs during the day; a mostly black screen runs cooler than a bright one.
The heat guard (section 10) protects it on the hottest days by dimming from about 70 °C on the chip and turning the screen off above 85 °C.

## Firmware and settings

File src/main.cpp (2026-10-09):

// Digital BMW-style emblem for the ESP32-S3 2.8" round display.
//
// The board starts its own Wi-Fi network ("BMW-Emblem" / "emblem123" by
// default). Join it from your phone and a control page opens automatically
// (or browse to http://192.168.4.1 or http://emblem.local). Optionally it can
// also join an existing network such as your phone's hotspot.
#ifndef EMBLEM_DIAG
#include <Arduino.h>
#include <DNSServer.h>
#include <JPEGDEC.h>
#include <ESPmDNS.h>
#include <LittleFS.h>
#include <Preferences.h>
#include <SD_MMC.h>
#include <Update.h>
#include <WebServer.h>
#include <WiFi.h>
#include <bootloader_random.h>
#include <esp_cache.h>
#include <esp_mac.h>
#include <esp_random.h>
#include <esp_sleep.h>
#include <driver/gpio.h>
#include <esp_sntp.h>

#include "display_config.h"
#include "i2c_bus.h"
#include "motion.h"
#include "renderer.h"
#include "rtc_clock.h"
#include "settings.h"
#include "web_ui.h"  // generated from web/index.html by tools/embed_web.py

#ifndef FW_BUILD
#define FW_BUILD "unknown"
#endif

static const size_t IMAGE_BYTES = size_t(Renderer::W) * Renderer::H * 2;
static const uint32_t FRAME_MS = 20;
static const uint32_t SAVE_DELAY_MS = 2000;
static const uint64_t ANIM_CAP_FLASH = 8ull << 20;  // biggest animation kept in internal flash
static const uint64_t ANIM_CAP_SD = 32ull << 20;    // ... and on a micro SD card

static esp_lcd_panel_handle_t panel;
static Renderer renderer;
static Settings settings;
static Preferences prefs;
static WebServer server(80);
static DNSServer dns;

static uint8_t lut5[32], lut6[64];
static bool softDim = LCD_BL_PIN < 0;
static bool forceFull = true;
static bool displayOk = false;
static uint32_t saveAt = 0;
static uint32_t restartAt = 0;
static uint32_t shutdownAt = 0;

// Power management state.
enum SleepReason : uint8_t { SLEEP_NONE = 0, SLEEP_OFF, SLEEP_LOWV };
RTC_DATA_ATTR static uint8_t sleepReason = SLEEP_NONE;  // survives deep sleep
// Crashes in a row (kept over restarts, cleared after a minute of running).
// After two, the newer extras stay off ("safe mode") so the page still works.
RTC_NOINIT_ATTR static uint32_t crashCount;
static bool safeMode = false;
static const char *resetReason = "";
static float volts = NAN;          // smoothed battery voltage, NAN if unknown
static uint32_t lastActivity = 0;  // last change made from the phone
static uint32_t showStart = 0;     // when car show mode started
static uint32_t lowSince = 0;      // when the voltage first dropped below the cutoff
static const uint32_t LOW_VOLT_GRACE_MS = 30000;  // ignore dips (e.g. engine cranking)
static const uint64_t LOW_VOLT_RECHECK_US = 10ull * 60 * 1000000;  // asleep: re-check every 10 min
static const float RESUME_MARGIN_V = 0.3f;

// What's on screen: a mode, and for MODE_IMAGE which slot. Usually the
// selected one, but the start-up clip and auto-cycle show others.
struct Item {
    uint8_t mode, slot;
};
static Item shown = {0xFF, 0};
static bool clipPlaying = false;   // start-up / welcome clip from a picture slot
static uint8_t clipSlot = 0;
static uint32_t clipStart = 0;
static bool resting = false;       // screen off while parked; a jolt wakes it
static int activeRule = -1;        // date-based design in force, -1 = none
static uint32_t welcomeAt = 0;     // welcome pending (waits to rule out a double-tap)
static uint32_t welcomeTaps = 0;
static const uint32_t WELCOME_QUIET_MS = 300000;  // still this long before a jolt means "welcome"
static void restTick(uint32_t now);
static void wake(bool welcome);
static void checkDateRule();
static bool cycleOn = false;       // auto-cycle has at least two designs
static bool cycleOverride = false; // showing cycleItem rather than the selection
static Item cycleItem = {0, 0};
static uint32_t cycleAt = 0;       // next change
static uint32_t cycleWaitLoops = UINT32_MAX;
static float motionFactor = 1;     // effects speed-up from acceleration
static bool nightNow = false;
static float brightNow = -1;       // backlight level being shown, %

// Heat guard. The ESP32-S3R8 on this board is rated to 65 °C ambient and the
// LCD panel (HD276001C40 class) to 70 °C operating / 80 °C storage, and a
// badge in summer sun gets hotter than that. The chip's own temperature sensor
// reads about 10-15 °C above the air around it, so: from HEAT_DIM_C the
// backlight (the main heat source) is capped, down to HEAT_MIN_PCT at
// HEAT_FULL_C; from HEAT_OFF_C the screen goes dark until the chip has cooled
// to HEAT_ON_C. Wi-Fi and the control page keep working throughout.
static const float HEAT_DIM_C = 70, HEAT_FULL_C = 80, HEAT_OFF_C = 85, HEAT_ON_C = 75;
static const uint8_t HEAT_MIN_PCT = 30;
enum HeatLevel : uint8_t { HEAT_OK = 0, HEAT_DIMMED, HEAT_DARK };
static float chipTemp = NAN;       // smoothed chip temperature, °C
static uint8_t heatLevel = HEAT_OK;
static uint8_t heatCap = 100;      // brightness allowed by the heat guard, %
static volatile bool ntpSynced = false;
static float uprightTilt = NAN;    // motion sensor set-up, step 1

// Crossfade between designs. Its clock starts with the first mixed frame
// (loading the new design can take a moment) and moves on by at most
// FADE_STEP_MS per frame, so a slow frame never skips most of the fade.
static const uint32_t FADE_MS = 600;
static const uint32_t FADE_STEP_MS = 60;
static uint16_t *fadeFrom = nullptr;  // what was on screen when the fade started
static uint32_t fadeStart = 0;        // non-zero while fading
static uint32_t fadeLast = 0;         // millis() of the last mixed frame, 0 = none yet
static uint32_t fadeMs = 0;           // how far the fade has got
static uint32_t fadeFrames = 0;

// ---------------------------------------------------------------------------
// Display output

// Logs to native USB and to UART0, so output shows up whichever port is used.
static void logf(const char *fmt, ...) {
    char buf[256];
    va_list args;
    va_start(args, fmt);
    vsnprintf(buf, sizeof(buf), fmt, args);
    va_end(args);
    Serial.print(buf);
#if ARDUINO_USB_CDC_ON_BOOT
    Serial0.print(buf);
#endif
}

static void *psramAlloc(size_t n) {
    return heap_caps_malloc(n, MALLOC_CAP_SPIRAM | MALLOC_CAP_8BIT);
}

// Car show mode has its own brightness; night dimming overrides both.
static uint8_t effectiveBrightness() {
    const uint8_t b = nightNow ? settings.nightBrightness
                    : settings.powerMode == POWER_CAR_SHOW ? settings.showBrightness : settings.brightness;
    return min(b, heatCap);
}

// Night by the emblem's clock (local time from the phone's time zone).
static bool nightTime() {
    if (!settings.autoDim || !clockValid()) return false;
    const int64_t local = int64_t(time(nullptr)) + settings.tzMin * 60;
    const int m = int((local % 86400 + 86400) % 86400 / 60);
    const int from = settings.nightFrom, to = settings.nightTo;
    return from <= to ? (m >= from && m < to) : (m >= from || m < to);
}

static void writeBacklight(float pct) {
#if LCD_BL_PIN >= 0
    ledcWrite(LCD_BL_PIN, uint32_t(pct * 1023 / 100 + 0.5f));
#endif
}

// The backlight follows effectiveBrightness() smoothly (see rampBrightness);
// software dimming (no backlight pin) switches straight away.
static void applyBrightness() {
    if (!displayOk) return;
    uint8_t pct = constrain(effectiveBrightness(), 5, 100);
    if (brightNow < 0) {
        brightNow = pct;
        writeBacklight(pct);
    }
    for (int i = 0; i < 32; i++) lut5[i] = i * pct / 100;
    for (int i = 0; i < 64; i++) lut6[i] = i * pct / 100;
    if (softDim) forceFull = true;
}

static void rampBrightness() {
    if (!displayOk || brightNow < 0) return;
    const float target = (resting || heatLevel == HEAT_DARK) ? 0 : constrain(effectiveBrightness(), 5, 100);
    const float diff = target - brightNow;
    if (diff == 0) return;
    const float step = fmaxf(0.5f, fabsf(diff) * 0.08f);
    brightNow = fabsf(diff) <= step ? target : brightNow + (diff > 0 ? step : -step);
    writeBacklight(brightNow);
}

// Double buffering: the panel shows one frame buffer while we fill the other,
// then we switch at the start of the next refresh, so a frame is never shown
// half-drawn (that was the tearing on the spinning roundel).
static uint16_t *fbs[2];
static int backFb = 1;
static Rect lastDirty = {0, 0, Renderer::W, Renderer::H};  // changed area of the previous frame
static SemaphoreHandle_t vsyncSem;

// With bounce buffers the driver switches to a new frame buffer when it has
// finished copying a whole frame out, so that's the moment to wait for.
static bool IRAM_ATTR onFrameDone(esp_lcd_panel_handle_t, const esp_lcd_rgb_panel_event_data_t *, void *) {
    BaseType_t woken = pdFALSE;
    xSemaphoreGiveFromISR(vsyncSem, &woken);
    return woken == pdTRUE;
}

static bool setupFrameBuffers() {
    void *a = nullptr, *b = nullptr;
    if (esp_lcd_rgb_panel_get_frame_buffer(panel, 2, &a, &b) != ESP_OK || !a || !b) return false;
    fbs[0] = static_cast<uint16_t *>(a);
    fbs[1] = static_cast<uint16_t *>(b);
    vsyncSem = xSemaphoreCreateBinary();
    esp_lcd_rgb_panel_event_callbacks_t cbs = {};
    cbs.on_bounce_frame_finish = onFrameDone;
    esp_lcd_rgb_panel_register_event_callbacks(panel, &cbs, nullptr);
    return true;
}

// The S3 can fall behind feeding the panel when PSRAM or flash is busy (e.g.
// saving settings), which leaves the picture shifted sideways ("drift").
// A restart re-syncs it at the next frame boundary, so it's invisible when
// nothing is wrong; call it after flash writes and now and then.
static void resyncDisplay() {
    if (panel) esp_lcd_rgb_panel_restart(panel);
}

// Shows the back buffer: flush it from the CPU cache, hand it to the driver
// (which switches buffers at the next vsync) and wait for that to happen, so
// the buffer we draw into next is no longer on screen.
// Time spent in present(), for the start-up animation's log line.
static uint32_t presentCopyUs = 0, presentSyncUs = 0, presentWaitUs = 0;

// rows y0..y0+rows-1 of the back buffer were written (only they need flushing).
static void swapBuffers(int y0 = 0, int rows = Renderer::H) {
    uint16_t *fb = fbs[backFb];
    uint32_t t = micros();
    if (rows > 0) {
        esp_cache_msync(fb + y0 * Renderer::W, size_t(rows) * Renderer::W * 2,
                        ESP_CACHE_MSYNC_FLAG_DIR_C2M | ESP_CACHE_MSYNC_FLAG_UNALIGNED);
    }
    presentSyncUs += micros() - t;
    t = micros();
    xSemaphoreTake(vsyncSem, 0);
    esp_lcd_panel_draw_bitmap(panel, 0, 0, Renderer::W, Renderer::H, fb);
    xSemaphoreTake(vsyncSem, pdMS_TO_TICKS(60));
    presentWaitUs += micros() - t;
    backFb ^= 1;
}

// Full-screen red, green, blue, white. If these don't appear, the panel isn't
// taking pixels at all (set-up commands or timing); if they do, the problem is
// in drawing the emblem.
static void showTestColours() {
    if (!panel || !fbs[0]) return;
    const uint16_t colours[] = {0xF800, 0x07E0, 0x001F, 0xFFFF};
    const char *names[] = {"red", "green", "blue", "white"};
    for (int i = 0; i < 4; i++) {
        logf("Test colour: %s\n", names[i]);
        uint16_t *fb = fbs[backFb];
        for (int p = 0; p < Renderer::W * Renderer::H; p++) fb[p] = colours[i];
        swapBuffers();
        delay(600);
    }
    forceFull = true;  // redraw the emblem afterwards
    lastDirty = {0, 0, Renderer::W, Renderer::H};
}

static uint32_t framesShown = 0;

static Rect unite(Rect a, Rect b) {
    if (a.empty()) return b;
    if (b.empty()) return a;
    int x0 = min(a.x, b.x), y0 = min(a.y, b.y);
    int x1 = max(a.x + a.w, b.x + b.w), y1 = max(a.y + a.h, b.y + b.h);
    return {int16_t(x0), int16_t(y0), int16_t(x1 - x0), int16_t(y1 - y0)};
}

// Copies the changed part of the rendered frame (brightness-scaled if dimming
// in software) into the back buffer and shows it. The back buffer last held
// the frame before the previous one, so it also needs the previous frame's
// changes; copying only that area keeps PSRAM traffic (and drift) down.
// During a crossfade the whole frame is mixed with the one it replaces.
// a5 = 0..32 (weight of b). All three channels at once: green moves to the
// top half of a 32-bit word so each channel has room to be multiplied.
static inline uint16_t mix565(uint16_t a, uint16_t b, uint32_t a5) {
    const uint32_t wa = (a | (uint32_t(a) << 16)) & 0x07E0F81F;
    const uint32_t wb = (b | (uint32_t(b) << 16)) & 0x07E0F81F;
    const uint32_t m = ((wa * (32 - a5) + wb * a5) >> 5) & 0x07E0F81F;
    return uint16_t(m | (m >> 16));
}

static void present(Rect r) {
    if (framesShown++ == 0) logf("First emblem frame sent to the display\n");
    const Rect full = {0, 0, Renderer::W, Renderer::H};
    // Never copy outside the frame buffer, whatever area we're given.
    {
        const int x0 = max<int>(r.x, 0), y0 = max<int>(r.y, 0);
        const int x1 = min<int>(r.x + r.w, Renderer::W), y1 = min<int>(r.y + r.h, Renderer::H);
        r = x1 > x0 && y1 > y0 ? Rect{int16_t(x0), int16_t(y0), int16_t(x1 - x0), int16_t(y1 - y0)} : Rect{0, 0, 0, 0};
    }
    const bool fading = fadeStart != 0;
    uint32_t t = 32;  // weight of the new frame, /32
    if (fading) {
        const uint32_t now = millis();
        fadeMs += fadeLast ? min<uint32_t>(now - fadeLast, FADE_STEP_MS) : FADE_STEP_MS / 2;
        fadeLast = now;
        fadeFrames++;
        t = min<uint32_t>(32, fadeMs * 32 / FADE_MS);
    }
    const Rect area = fading ? full : unite(r, lastDirty);
    lastDirty = fading ? full : r;
    const uint16_t *src = renderer.frame();
    uint16_t *dst = fbs[backFb];
    const bool scale = softDim && effectiveBrightness() < 100;
    const uint32_t copyStart = micros();
    for (int y = area.y; y < area.y + area.h; y++) {
        const size_t off = size_t(y) * Renderer::W + area.x;
        if (!scale && !fading) {
            memcpy(dst + off, src + off, area.w * 2);
            continue;
        }
        int x0 = 0, x1 = area.w;
        if (fading) {
            // Only the round screen; the corners aren't visible.
            const float fy = y + 0.5f - Renderer::H / 2.0f, h2 = 240.5f * 240.5f - fy * fy;
            const float half = h2 > 0 ? sqrtf(h2) : 0;
            x0 = max(0, int(Renderer::W / 2 - half));
            x1 = min<int>(area.w, int(ceilf(Renderer::W / 2 + half)));
        }
        for (int x = x0; x < x1; x++) {
            uint16_t p = fading ? mix565(fadeFrom[off + x], src[off + x], t) : src[off + x];
            if (scale) p = (lut5[p >> 11] << 11) | (lut6[(p >> 5) & 63] << 5) | lut5[p & 31];
            dst[off + x] = p;
        }
    }
    presentCopyUs += micros() - copyStart;
    swapBuffers(area.y, area.h);
    if (fading && t >= 32) {
        logf("Crossfade: %u steps over %u ms\n", unsigned(fadeFrames), unsigned(millis() - fadeStart));
        fadeStart = 0;
        forceFull = true;  // the other buffer still holds a mixed frame
    }
}

// Starts a crossfade from what's on screen now.
static void startFade() {
    if (!fadeFrom) fadeFrom = static_cast<uint16_t *>(psramAlloc(IMAGE_BYTES));
    if (!fadeFrom) return;
    // The front buffer is what's showing (already dimmed when dimming in software).
    memcpy(fadeFrom, softDim ? renderer.frame() : fbs[backFb ^ 1], IMAGE_BYTES);
    fadeStart = millis() | 1;
    fadeLast = fadeMs = fadeFrames = 0;
}

// ---------------------------------------------------------------------------
// Storage

// Pictures and animations go on the micro SD card when one is fitted at
// start-up, otherwise in the internal flash (LittleFS).
static bool sdOk = false;

static fs::FS &media() {
    return sdOk ? static_cast<fs::FS &>(SD_MMC) : static_cast<fs::FS &>(LittleFS);
}

static uint64_t mediaTotal() {
    return sdOk ? SD_MMC.totalBytes() : LittleFS.totalBytes();
}

static uint64_t mediaUsed() {
    return sdOk ? SD_MMC.usedBytes() : LittleFS.usedBytes();
}

static String mediaDir() {
    return sdOk ? "/emblem" : "";
}

static String imagePath(int slot) {
    return mediaDir() + "/img" + String(slot) + ".bin";
}

static String animPath(int slot) {
    return mediaDir() + "/anim" + String(slot) + ".mjp";
}

static String uploadPath() {
    return mediaDir() + "/upload.tmp";
}
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
void loop() {
    uint32_t t = millis();
    dns.processNextRequest();
    slowCheck(t, "DNS");
    server.handleClient();
    if (millis() - t > 250) logf("Slow: web request %s took %u ms\n", server.uri().c_str(), unsigned(millis() - t));
    t = millis();

    static uint32_t lastFrame = 0;
    uint32_t now = millis();

    // Motion: speed-up from acceleration, double-tap for the next design.
    if (motionPresent()) {
        const float k = constrain((motionBoost() - 0.05f) / 0.35f, 0.0f, 1.0f);
        motionFactor = 1 + settings.motionReact / 100.0f * 2 * k;
        static uint32_t tapsSeen = motionDoubleTaps();
        const uint32_t taps = motionDoubleTaps();
        if (taps != tapsSeen) {
            tapsSeen = taps;
            welcomeAt = 0;  // it was a double-tap, not a welcome jolt
            if (resting) {
                wake(true);
            } else if (settings.doubleTap && displayOk && !clipPlaying && !renderer.introRunning()) {
                logf("Double-tap: next design\n");
                lastActivity = now;
                nextItem();
            }
        }
        // A jolt after the car has been still (a door or the boot closing):
        // welcome. Waits a moment in case it's the first tap of a double-tap.
        static uint32_t joltsSeen = motionJolts();
        const uint32_t jolts = motionJolts();
        if (jolts != joltsSeen) {
            joltsSeen = jolts;
            if (resting || (settings.welcomeOn && motionQuietBeforeJolt() >= WELCOME_QUIET_MS)) {
                welcomeAt = (now + 700) | 1;
                welcomeTaps = motionDoubleTaps();
            }
        }
        if (welcomeAt && int32_t(now - welcomeAt) >= 0) {
            welcomeAt = 0;
            if (motionDoubleTaps() == welcomeTaps && displayOk && !renderer.introRunning()) wake(true);
        }
    }
    renderer.setBoost(motionFactor);
    if (ntpSynced) {
        ntpSynced = false;
        rtcSaveSystemTime();
        logf("Clock set from the internet\n");
    }
    slowCheck(t, "motion");
    if (displayOk) {
        clipTick(now);
        cycleTick(now);
        slowCheck(t, "auto-cycle / clip");
        if (!resting) stepAnimation(now);
        slowCheck(t, "animation frame");
    }
    static uint32_t lastResync = 0;
    if (displayOk && now - lastResync >= 1000) {
        lastResync = now;
        resyncDisplay();
    }
    if (displayOk && now - lastFrame >= FRAME_MS && !((resting || heatLevel == HEAT_DARK) && brightNow <= 0)) {
        lastFrame = now;
        rampBrightness();
        // Start-up animation frame rate, for the log.
        static uint32_t introFrames = 0, introMs = 0, introMax = 0, introDrawUs = 0, introPx0 = 0;
        const bool introFrame = renderer.introRunning();
        if (introFrame && !introFrames) {
            presentCopyUs = presentSyncUs = presentWaitUs = 0;
            introPx0 = renderer.introPixels();
        }
        const uint32_t frameStart = millis();
        const uint32_t drawStart = micros();
        // The start-up animation and the stripes draw straight into the frame
        // buffer that is shown next (no copy), unless dimming in software or
        // crossfading.
        const bool direct = introFrame || shown.mode == MODE_STRIPES;
        uint16_t *target = direct && !softDim && !fadeStart && !forceFull ? fbs[backFb] : nullptr;
        Rect r = renderer.render(now, target);
        if (introFrame) introDrawUs += micros() - drawStart;
        if (forceFull || fadeStart) {
            r = {0, 0, Renderer::W, Renderer::H};
            forceFull = false;
        }
        if (renderer.drewIntoTarget()) {
            if (framesShown++ == 0) logf("First emblem frame sent to the display\n");
            lastDirty = {0, 0, Renderer::W, Renderer::H};  // frame() is behind: copy it all next time
            swapBuffers(r.y, r.h);
        } else if (!r.empty()) {
            present(r);
        }
        if (introFrame) {
            const uint32_t ms = millis() - frameStart;
            introFrames++;
            introMs += ms;
            introMax = max(introMax, ms);
            if (!renderer.introRunning()) {
                logf("Start-up animation: %u frames, %u ms each on average (%.0f fps), slowest %u ms\n",
                     unsigned(introFrames), unsigned(introMs / introFrames), 1000.0f * introFrames / max<uint32_t>(introMs, 1),
                     unsigned(introMax));
                logf("  per frame: drawing %u ms, copying %u ms, cache flush %u ms, waiting for the panel %u ms\n",
                     unsigned(introDrawUs / 1000 / introFrames), unsigned(presentCopyUs / 1000 / introFrames),
                     unsigned(presentSyncUs / 1000 / introFrames), unsigned(presentWaitUs / 1000 / introFrames));
                const uint32_t px = renderer.introPixels() - introPx0;
                logf("  %u pixels drawn per frame, %.2f us each\n", unsigned(px / introFrames),
                     px ? float(introDrawUs) / px : 0.0f);
                introFrames = introMs = introMax = introDrawUs = 0;
            }
        }
        slowCheck(t, "drawing");
    }

    if (crashCount && now > 60000) {
        crashCount = 0;  // running fine
        logf("Running for a minute: crash counter cleared\n");
    }
    static uint32_t lastPowerTick = 0;
    if (now - lastPowerTick >= 1000) {
        lastPowerTick = now;
        powerTick(now);
        staTick(now);
        slowCheck(t, "once-a-second checks");
    }
    bootButtonTick(now);
    if (shutdownAt && int32_t(now - shutdownAt) >= 0) shutdownNow(SLEEP_OFF);
    if (saveAt && int32_t(now - saveAt) >= 0) saveSettings();
    if (restartAt && int32_t(now - restartAt) >= 0) ESP.restart();
    delay(1);
}
#endif  // EMBLEM_DIAG

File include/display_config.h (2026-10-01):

#pragma once
// Pin-out for the Waveshare ESP32-S3-LCD-2.8C (2.8" round 480x480):
// ST7701S RGB panel, TCA9554 I/O expander on I2C (EXIO1 = LCD reset,
// EXIO3 = LCD SPI chip select), backlight PWM on GPIO6. See
// https://www.waveshare.com/wiki/ESP32-S3-LCD-2.8C
#include <Arduino.h>
#include <Wire.h>

#include "../src/i2c_bus.h"
#include <driver/spi_master.h>
#include <esp_lcd_panel_ops.h>
#include <esp_lcd_panel_rgb.h>

#define I2C_SDA 15
#define I2C_SCL 7
#define PCA9554_ADDR 0x20

// Expander outputs
#define EXIO_LCD_RST 0  // EXIO1
#define EXIO_TP_RST 1   // EXIO2
#define EXIO_LCD_CS 2   // EXIO3
#define EXIO_SD_D3 3    // EXIO4

// Micro SD card (SD_MMC, 1-bit mode). CLK/CMD are shared with the display's
// set-up bus, which is only used once at boot.
#define SD_CLK 2
#define SD_CMD 1
#define SD_D0 42

// Battery sense: the board's LiPo connector through a 1:3 divider (Waveshare
// BAT_Driver: volts = mV * 3 / 1000 / 0.980952). A 12 V car battery can be
// read with an INA219 module on the I2C connector instead (up to 26 V).
#define BAT_ADC_PIN 4
#define BAT_DIVIDER (3.0f / 0.980952f)
#define INA219_ADDR 0x40

// Backlight PWM pin. Set to -1 to dim in software instead.
#ifndef LCD_BL_PIN
#define LCD_BL_PIN 6
#endif

// Panel set-up program: OP_CMD c | OP_DATA n d1..dn | OP_DELAY ms.
enum : uint8_t { OP_CMD = 1, OP_DATA, OP_DELAY };

// Start-up sequence from Waveshare's ESP32-S3-LCD-2.8C demo
// (Display_ST7701.cpp in ESP32-S3-LCD-2.8C-Demo.zip), command for command.
static const uint8_t waveshare_2_8c_init_operations[] = {
        OP_CMD, 0xFF,
    OP_DATA, 5, 0x77, 0x01, 0x00, 0x00, 0x13,
    OP_CMD, 0xEF,
    OP_DATA, 1, 0x08,
    OP_CMD, 0xFF,
    OP_DATA, 5, 0x77, 0x01, 0x00, 0x00, 0x10,
    OP_CMD, 0xC0,
    OP_DATA, 2, 0x3B, 0x00,
    OP_CMD, 0xC1,
    OP_DATA, 2, 0x10, 0x0C,
    OP_CMD, 0xC2,
    OP_DATA, 2, 0x07, 0x0A,
    OP_CMD, 0xC7,
    OP_DATA, 1, 0x00,
    OP_CMD, 0xCC,
    OP_DATA, 1, 0x10,
    OP_CMD, 0xCD,
    OP_DATA, 1, 0x08,
    OP_CMD, 0xB0,
    OP_DATA, 16, 0x05, 0x12, 0x98, 0x0E, 0x0F, 0x07, 0x07, 0x09, 0x09, 0x23, 0x05, 0x52, 0x0F, 0x67, 0x2C, 0x11,
    OP_CMD, 0xB1,
    OP_DATA, 16, 0x0B, 0x11, 0x97, 0x0C, 0x12, 0x06, 0x06, 0x08, 0x08, 0x22, 0x03, 0x51, 0x11, 0x66, 0x2B, 0x0F,
    OP_CMD, 0xFF,
    OP_DATA, 5, 0x77, 0x01, 0x00, 0x00, 0x11,
    OP_CMD, 0xB0,
    OP_DATA, 1, 0x5D,
    OP_CMD, 0xB1,
    OP_DATA, 1, 0x3E,
    OP_CMD, 0xB2,
    OP_DATA, 1, 0x81,
    OP_CMD, 0xB3,
    OP_DATA, 1, 0x80,
    OP_CMD, 0xB5,
    OP_DATA, 1, 0x4E,
    OP_CMD, 0xB7,
    OP_DATA, 1, 0x85,
    OP_CMD, 0xB8,
    OP_DATA, 1, 0x20,
    OP_CMD, 0xC1,
    OP_DATA, 1, 0x78,
    OP_CMD, 0xC2,
    OP_DATA, 1, 0x78,
    OP_CMD, 0xD0,
    OP_DATA, 1, 0x88,
    OP_CMD, 0xE0,
    OP_DATA, 3, 0x00, 0x00, 0x02,
    OP_CMD, 0xE1,
    OP_DATA, 11, 0x06, 0x30, 0x08, 0x30, 0x05, 0x30, 0x07, 0x30, 0x00, 0x33, 0x33,
    OP_CMD, 0xE2,
    OP_DATA, 12, 0x11, 0x11, 0x33, 0x33, 0xF4, 0x00, 0x00, 0x00, 0xF4, 0x00, 0x00, 0x00,
    OP_CMD, 0xE3,
    OP_DATA, 4, 0x00, 0x00, 0x11, 0x11,
    OP_CMD, 0xE4,
    OP_DATA, 2, 0x44, 0x44,
    OP_CMD, 0xE5,
    OP_DATA, 16, 0x0D, 0xF5, 0x30, 0xF0, 0x0F, 0xF7, 0x30, 0xF0, 0x09, 0xF1, 0x30, 0xF0, 0x0B, 0xF3, 0x30, 0xF0,
    OP_CMD, 0xE6,
    OP_DATA, 4, 0x00, 0x00, 0x11, 0x11,
    OP_CMD, 0xE7,
    OP_DATA, 2, 0x44, 0x44,
    OP_CMD, 0xE8,
    OP_DATA, 16, 0x0C, 0xF4, 0x30, 0xF0, 0x0E, 0xF6, 0x30, 0xF0, 0x08, 0xF0, 0x30, 0xF0, 0x0A, 0xF2, 0x30, 0xF0,
    OP_CMD, 0xE9,
    OP_DATA, 2, 0x36, 0x01,
    OP_CMD, 0xEB,
    OP_DATA, 7, 0x00, 0x01, 0xE4, 0xE4, 0x44, 0x88, 0x40,
    OP_CMD, 0xED,
    OP_DATA, 16, 0xFF, 0x10, 0xAF, 0x76, 0x54, 0x2B, 0xCF, 0xFF, 0xFF, 0xFC, 0xB2, 0x45, 0x67, 0xFA, 0x01, 0xFF,
    OP_CMD, 0xEF,
    OP_DATA, 6, 0x08, 0x08, 0x08, 0x45, 0x3F, 0x54,
    OP_CMD, 0xFF,
    OP_DATA, 5, 0x77, 0x01, 0x00, 0x00, 0x00,
    OP_CMD, 0x11,
    OP_DELAY, 120,
        OP_CMD, 0x3A,
    OP_DATA, 1, 0x66,
    OP_CMD, 0x36,
    OP_DATA, 1, 0x00,
    OP_CMD, 0x35,
    OP_DATA, 1, 0x00,
    OP_CMD, 0x29,
};

// RGB bus settings. 18 MHz is what Waveshare's ESP-IDF demo uses (~65 Hz
// refresh); 30 MHz is their Arduino demo (~108 Hz, more PSRAM load, more
// prone to drift); 12 MHz is the lightest on PSRAM.
struct PanelType {
    const char *name;
    uint32_t pclkHz;
    lcd_clock_source_t clkSrc;
    size_t bounceBufferPx;
};

static const PanelType PANEL_TYPES[] = {
    {"18 MHz (recommended)", 18000000, LCD_CLK_SRC_PLL240M, 480 * 20},
    {"30 MHz (Waveshare demo)", 30000000, LCD_CLK_SRC_PLL240M, 480 * 20},
    {"12 MHz (lightest)", 12000000, LCD_CLK_SRC_PLL240M, 480 * 20},
};
static const uint8_t PANEL_TYPE_COUNT = sizeof(PANEL_TYPES) / sizeof(PANEL_TYPES[0]);

static uint8_t expanderOut = 0;

inline bool expanderWrite(uint8_t reg, uint8_t val) {
    I2CLock lock;
    Wire.beginTransmission(PCA9554_ADDR);
    Wire.write(reg);
    Wire.write(val);
    return Wire.endTransmission() == 0;
}
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

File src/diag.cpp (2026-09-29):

// Hardware check, built only by the "diag" environments in platformio.ini:
//   pio run -e diag -t upload && pio device monitor -e diag
// It skips the display entirely, starts an open Wi-Fi network "EMBLEM-TEST"
// and prints what it finds to both serial outputs (native USB and UART0), so
// it works whichever USB-C port the cable is in.
#ifdef EMBLEM_DIAG
#include <Arduino.h>
#include <WebServer.h>
#include <WiFi.h>
#include <Wire.h>
#include <esp_chip_info.h>

#include "display_config.h"

static WebServer server(80);
static String scanResult;

static void logBoth(const String &s) {
    Serial.println(s);
#if ARDUINO_USB_CDC_ON_BOOT
    Serial0.println(s);
#endif
}

static const char *resetReason() {
    switch (esp_reset_reason()) {
        case ESP_RST_POWERON: return "power on";
        case ESP_RST_SW: return "software restart";
        case ESP_RST_PANIC: return "CRASH (panic)";
        case ESP_RST_INT_WDT: return "CRASH (interrupt watchdog)";
        case ESP_RST_TASK_WDT: return "CRASH (task watchdog)";
        case ESP_RST_WDT: return "CRASH (watchdog)";
        case ESP_RST_BROWNOUT: return "BROWNOUT (power supply too weak)";
        default: return "other";
    }
}

static String i2cScan() {
    String out;
    for (uint8_t a = 1; a < 127; a++) {
        Wire.beginTransmission(a);
        if (Wire.endTransmission() == 0) {
            char buf[8];
            snprintf(buf, sizeof(buf), "0x%02X ", a);
            out += buf;
        }
    }
    return out.length() ? out : String("nothing found");
}

static String report() {
    String r;
    r += "Chip: " + String(ESP.getChipModel()) + " rev " + String(ESP.getChipRevision()) + "\n";
    r += "Last reset: " + String(resetReason()) + "\n";
    r += "Flash size: " + String(ESP.getFlashChipSize() / 1024 / 1024) + " MB\n";
    r += "PSRAM in use: " + String(psramFound() ? "yes, " + String(ESP.getPsramSize() / 1024) + " KB" : String("no")) + "\n";
    r += "Free heap: " + String(ESP.getFreeHeap() / 1024) + " KB\n";
    r += "I2C devices (SDA 15, SCL 7): " + scanResult + "\n";
    r += "Uptime: " + String(millis() / 1000) + " s\n";
    return r;
}

static void page() {
    String h = "<!doctype html><meta name=viewport content='width=device-width'><title>Emblem test</title>"
               "<body style='font:16px sans-serif;background:#111;color:#eee;padding:16px'>"
               "<h2>Emblem hardware test</h2><pre>" + report() + "</pre>"
               "<p><a style='color:#6af' href='/bl?on=1'>Backlight GPIO6 ON</a> &nbsp; "
               "<a style='color:#6af' href='/bl?on=0'>OFF</a></p>"
               "<p><a style='color:#6af' href='/'>Refresh</a></p>";
    server.send(200, "text/html", h);
}

void setup() {
    Serial.begin(115200);
#if ARDUINO_USB_CDC_ON_BOOT
    Serial0.begin(115200);
#endif
    delay(2000);
    logBoth("\n=== Emblem hardware test ===");

    Wire.begin(I2C_SDA, I2C_SCL);
    scanResult = i2cScan();

    pinMode(6, OUTPUT);
    digitalWrite(6, HIGH);  // backlight on (screen stays black but may glow)

    WiFi.mode(WIFI_AP);
    bool ap = WiFi.softAP("EMBLEM-TEST");
    logBoth(String("Wi-Fi EMBLEM-TEST: ") + (ap ? "started, open http://192.168.4.1" : "FAILED"));

    server.on("/", page);
    server.on("/bl", [] {
        digitalWrite(6, server.arg("on") == "1" ? HIGH : LOW);
        server.sendHeader("Location", "/");
        server.send(302);
    });
    server.begin();
    logBoth(report());
}

void loop() {
    server.handleClient();
    static uint32_t last = 0;
    if (millis() - last > 5000) {
        last = millis();
        logBoth(report());
    }
    delay(2);
}
#endif

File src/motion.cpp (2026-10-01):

#ifndef EMBLEM_DIAG
#include "motion.h"

#include <Arduino.h>
#include <Wire.h>
#include <math.h>

#include "i2c_bus.h"

namespace {

// QMI8658 registers.
const uint8_t REG_WHO_AM_I = 0x00;  // reads 0x05
const uint8_t REG_CTRL1 = 0x02;     // serial interface
const uint8_t REG_CTRL2 = 0x03;     // accelerometer range + data rate
const uint8_t REG_CTRL5 = 0x06;     // low-pass filters
const uint8_t REG_CTRL7 = 0x08;     // sensor enables
const uint8_t REG_AX_L = 0x35;      // AX_L, AX_H, AY_L, AY_H, AZ_L, AZ_H
const uint8_t REG_RESET = 0x60;

const float LSB_PER_G = 4096.0f;  // +-8 g range
const uint32_t PERIOD_MS = 10;    // 100 Hz
const float DT = PERIOD_MS / 1000.0f;

uint8_t addr = 0;
volatile float tiltDeg = 0;
volatile float boost = 0;
volatile float vibration = 0;  // RMS of the vibration, g
volatile uint32_t doubleTaps = 0;
volatile float peakJolt = 0;  // biggest recent jolt, g (fades over ~2 s)
volatile uint32_t jolts = 0;
volatile float joltThreshold = 0.25f;
volatile uint32_t lastMovement = 0;  // millis() of the last movement
volatile uint32_t quietBeforeJolt = 0;
uint32_t burstQuiet = 0, burstStart = 0, lastJolt = 0;
const float MOVEMENT_G = 0.06f;      // smaller jolts don't count as movement
volatile uint8_t tapSensitivity = 0;
volatile bool enabled = true;

bool writeReg(uint8_t reg, uint8_t val) {
    I2CLock lock;
    Wire.beginTransmission(addr);
    Wire.write(reg);
    Wire.write(val);
    return Wire.endTransmission() == 0;
}
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

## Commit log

2026-09-29 Digital emblem firmware with phone web control
    - Renderer for roundel (static/spinning), M stripes, solid/pulse, picture and text modes
    - Vector stroke font for ring lettering and text mode
    - Wi-Fi access point + captive portal web UI (embedded, gzipped) with live preview
    - Picture upload (5 slots, crop/zoom/rotate in browser), settings saved to NVS
    - Optional join-network mode and OTA firmware update from the page
    - Host preview renderer and mock server for working without hardware
    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
2026-09-29 Fix blank display / missing Wi-Fi at boot
    - Start Wi-Fi and the web page before the display so a display failure
    can't take them down; log each start-up step to serial
    - Drive the backlight on GPIO6 and hold the panel's SPI chip select
    (expander EXIO3) low while its init commands are sent
    - Selectable panel init sequence (default: 2.8in round TL028WVC01),
    switchable from the phone page, which warns when the display didn't start
    - Drop the ESP32-only -mfix-esp32-psram-cache-issue flag and the stale
    compile_commands.json that confused the VS Code checker
    Claude-Session: https://claude.ai/code/session_01Sy1MopW46p6ESWSBAk4gEh
    [display_config.h, main.cpp, settings.h]
2026-09-29 Add display-free hardware test firmware; log to both serial ports
    - src/diag.cpp (envs diag and diag-psram): open Wi-Fi EMBLEM-TEST, chip /
    flash / PSRAM / reset-reason / I2C report on serial and a web page
    - Main firmware logs to native USB and UART0
    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
    [diag.cpp, main.cpp]
2026-09-29 Fix boot (board has quad PSRAM) and add animation uploads
    - memory_type qio_opi -> qio_qspi: the octal setting stopped the board
    before setup() ran (no display, Wi-Fi or serial)
    - Picture slots can hold animations: the phone turns GIFs / animated WebP
    (ImageDecoder) and videos into 480x480 JPEG frames (EMJ1 file, <= 3 MB,
    quality/frame-rate reduced automatically to fit); firmware keeps it in
    PSRAM and decodes frames with JPEGDEC
    - Picture editor: Fill / Fit / Fit circle, background colour, pinch zoom,
    drag, rotate, re-centre, live preview, upload progress, storage usage
    Claude-Session: https://claude.ai/code/session_01Sy1MopW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
    [main.cpp]
2026-09-29 Use Waveshare's ESP32-S3-LCD-2.8C panel init and timings
    - ST7701S start-up sequence converted from Waveshare's demo
    (Display_ST7701.cpp) and made the default panel type, with the demo's
    RGB timings (HPW 8 / HBP 10 / HFP 50, VPW 2 / VBP 18 / VFP 8), 16 MHz pclk
    - Serial on UART0: the board's USB-C goes through a CH343 USB-UART chip
    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
2026-09-29 Bigger uploads and micro SD card support
    - Animations stream frame by frame from storage instead of loading into
    PSRAM, so the size limit is free space: up to 8 MB in flash, 32 MB on SD
    - Micro SD card (SD_MMC 1-bit on GPIO2/1/42, D3 via EXIO4, as in
    Waveshare's demo) is used for pictures when present at boot
    - LittleFS grown to ~12 MB (app slots 3 MB -> 2 MB, firmware is ~1 MB)
    - 10 picture slots; videos up to 60 s; the page estimates size up front
    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
    [partitions.csv]
2026-09-29 Back to octal PSRAM (qio_opi); quieter log
    The board's PSRAM is octal (Waveshare demo: CONFIG_SPIRAM_MODE_OCT);
    qio_qspi gave 'PSRAM ID read error' so the display could never start.
    The earlier 'quad works' reading came from the diag-psram env, which was
    the last one flashed when Upload built every environment.
    Also list picture slots from one directory scan instead of probing each
    file, and set CORE_DEBUG_LEVEL=0 to drop the core's per-request noise.
    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
    [diag.cpp, main.cpp]
2026-09-29 Add display colour test (at boot and from the phone page)
    Fills the screen red, green, blue, white after the panel is set up and
    logs each step plus the first emblem frame, to tell a panel/set-up fault
    apart from a drawing fault.
    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
2026-09-29 Send panel set-up commands over hardware SPI
    The colour test ran but nothing reached the glass, so the panel wasn't
    taking its set-up commands. Arduino_SWSPI bit-bangs the 9-bit words with
    no delay between edges; now they go through the SPI peripheral exactly as
    Waveshare's demo does (mode 0, 1 D/C command bit + 8 address bits, 10 MHz),
    and the bus is released afterwards for the SD card.
    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
2026-09-29 Drive the RGB panel with esp_lcd directly, like Waveshare's demo
    The panel gets its set-up commands and the firmware draws frames, but the
    glass stayed dark while Waveshare's demo works on the same board. Take
    Arduino_GFX out of the pixel path: create the RGB panel with
    esp_lcd_new_rgb_panel (demo pins/timings, PSRAM frame buffer) and push
    frames with esp_lcd_panel_draw_bitmap. Backlight PWM now matches the demo
    (20 kHz, 10-bit).
    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
2026-09-29 Move to Arduino core 3 and mirror Waveshare's display setup exactly
    The panel accepted power and backlight but never showed pixels with the
    IDF 4.4 RGB driver, while Waveshare's demo works on the same board. Build
    on pioarduino (Arduino 3.1 / ESP-IDF 5.3, the demo's generation) and set
    the RGB panel up like the demo: PLL240M clock, 30 MHz pixel clock, 10-line
    bounce buffers, PSRAM frame buffer. The ST7701 commands are the demo's,
    sent over hardware SPI. Arduino_GFX is no longer used.
    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
    [display_config.h, main.cpp]
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2026-09-29 Stop tearing and picture drift
    - Swap frame buffers on the bounce-buffer frame-finished event (when the
    driver actually switches buffers with bounce buffering) instead of vsync
    - Recover from ESP32-S3 RGB drift (picture stuck shifted sideways after
    PSRAM/flash stalls): esp_lcd_rgb_panel_restart() after flash writes and
    once a second; it takes effect at a frame boundary
    - Less PSRAM load: 18 MHz pixel clock by default (Waveshare ESP-IDF demo;
    30 and 12 MHz selectable), 20-line bounce buffers, and copy only the
    changed area into the back buffer
    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
    [display_config.h, main.cpp]
2026-09-29 Resync the display right after reading pictures from flash
    Loading a picture (up to 460 KB) or an animation frame from flash stalls
    the RGB feed and could leave the image shifted until the 1 s resync.
    Restart the stream straight after those reads.
    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
    [main.cpp]
2026-09-29 Nicer artwork, start-up animation, power management and a new phone UI
    Display
    - Roundel: torus-shaded chrome rims with specular highlight, glossy ring,
    embossed gradient letters with soft shadow, domed glossy quarters;
    ordered dithering to avoid banding
    - Stripes: carbon-fibre twill with sheen, rounded stripe shading, drop
    shadow and vignette. Text: gradient letters, soft shadow, lit background
    - Start-up animation (ring sweep with spark, quarters spin/zoom in, glint)
    replaces the colour-test flashes; can be turned off
    - Solid colour mode removed
    Power
    - Normal mode auto-off (5 min - 4 h from power-on / last change)
    - Car show mode: stays on for 1-24 h or until low battery, own bri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
    [display_config.h, main.cpp, renderer.cpp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]
2026-09-29 Show the hotspot address on the emblem when it joins
    Android browsers don't resolve emblem.local and Android hotspots change
    subnet, so when the emblem gets an address on the hotspot it shows
    HOTSPOT + the IP on screen for 6 s (toggle in Settings), and registers
    the hostname "emblem" so it's named in the phone's hotspot device list.
    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
    [main.cpp, settings.h]
2026-09-30 Fix glitchy frames in animations made from phone videos
    Phones fire the video "seeked" event before the decoder has delivered
    the new frame, so frames were grabbed too early: many came out as a
    repeat of an older frame and some as half-decoded, blocky smears, which
    showed on the emblem as jumps and jagged glitches. Wait for the new frame
    (requestVideoFrameCallback, checked against the target time) before
    drawing it, and stop the preview playback before encoding.
    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
2026-09-30 Phone (HEVC) videos without converting, in any browser
    Firefox can't play HEVC, which most phone cameras record. The page now
    reads the MP4 itself and decodes the frames with a WebAssembly HEVC
    decoder that the emblem serves (/hevc.js, /hevc.wasm, ~110 KB gzipped):
    - web/vendor/hevc: hevc.js (MIT) built with a fix for videos coded with
    tiles (Samsung): CABAC contexts weren't reset at each tile, so only the
    first tile decoded. Bit-exact against ffmpeg on a Samsung clip; the
    project's conformance tests still pass. Patch and rebuild steps included.
    - MP4 demuxer in the page: samples, B-frame timing, rotation matrix
    (portrait videos come out upright), colour description.
    - HDR (PQ / HLG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
    [main.cpp]
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2026-10-01 Fix I2C sharing with the motion task; crash detection and safe mode
    - Hold one lock for each whole I2C transaction (Wire releases its own lock
    before the bytes are read out, so the motion task could corrupt clock /
    INA219 / expander reads, and vice versa)
    - Motion task: 100 Hz, bigger stack, backs off if the sensor stops answering
    instead of hogging the bus; back to the default 100 kHz bus speed
    - Count crashes in a row; after two, start in safe mode (no motion sensor,
    no start-up animation) so the page still works, and show it on the page
    - Last restart reason and uptime shown under Settings > Firmware
    - 'Use the motion sensor' switch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
    [display_config.h, main.cpp, motion.cpp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]
2026-10-01 Keep the emblem's network usable when the hotspot is away; timing logs
    - No automatic hotspot reconnect: while searching, the ESP32 hops channels
    and its own network stalls (phones connect but pages don't load).
    Retry once a minute, and only while no phone is on the emblem's network.
    - Serial log: time taken by each start-up step, and any slow part of the
    main loop (web request, drawing, animation, checks) with its name
    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
    [main.cpp]
2026-10-01 Start-up animation can't be skipped by a slow frame
    The intro used the wall clock, so if drawing stalled at start-up (storage,
    display re-sync, Wi-Fi) the animation was over before the next frame was
    drawn and the finished emblem appeared straight away. It now keeps its own
    clock that advances at most 0.1 s per frame. Also fixes the intro ending at
    once when started part-way through a loop pass (welcome), and re-syncs the
    display just before it starts.
    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
    [main.cpp, renderer.cpp]
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2026-10-01 Fix crash during the start-up animation; build the roundel faster
    - The intro's changed-area rectangle could reach past the screen edge
    (e.g. y = -8 at the start of the ring sweep) and present() copied pixels
    to before the frame buffer, overwriting the display DMA's state; the
    next DMA interrupt crashed (LoadProhibited in gdma_default_tx_isr).
    Rectangles are now clipped to the screen in the renderer and present().
    - Roundel build: skip pixels outside the badge, rule out the gaps between
    letters before any trig, use the angle table instead of atan2, and a
    separable gloss instead of expf per pixel (~3 s on the board before).
    - Rejoin the hotspot every 20 s instead of every minute.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
    [main.cpp, renderer.cpp]
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2026-10-01 Undo display-on-core-0; time each part of an animation frame
    - Running the panel's interrupts on core 0 didn't speed drawing up (105 vs
    113 ms per frame) and tore the picture: removed (the settings byte stays,
    unused, so stored settings still load).
    - The cache flush before showing a frame now covers only the rows that
    changed instead of the whole screen.
    - While the quarters grow in, only the disc's current size is redrawn.
    - Log how each start-up animation frame splits into drawing, copying,
    cache flush and waiting for the panel.
    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
    [main.cpp, renderer.cpp, settings.h]
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2026-10-01 Start-up animation: tight loops for the ring sweep and disc, run from internal RAM, gentler spin
    The ring sweep reuses the radius and angle it already worked out, and the
    disc works out per row what doesn't change along it, so most pixels skip the
    general per-pixel function. The drawing code runs from internal RAM. The
    quarters turn 1.5 times instead of 2.5 while settling, which strobes less at
    the frame rate the board manages. The log now shows pixels drawn per frame
    and the cost of each.
    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
    [main.cpp, renderer.cpp]
2026-10-02 Faster roundel changes, and a colour wheel in the web page
    The roundel was rebuilt from scratch (about 2.6 s on the board) on every
    settings change and every auto-cycle switch. Now:
    - only changes to its colours, lettering or angle rebuild it, and the
    carbon fibre behind the stripes has its own buffer, so switching designs
    doesn't throw the roundel away;
    - its shape is worked out once as a per-pixel mix of the rim, ring,
    letter and quarter colours, so a colour change only remixes it
    (about a fifth of the time; at most one shade step different).
    The page gets its own colour picker, since Firefox on Android only offers
    a small grid of colours: a hue / saturation wheel, brightness and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
    [renderer.cpp]
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2026-10-02 Crossfades: every fade gets its steps
    The fade's clock started before the new design was loaded and each mixed
    frame was slow, so a fade often showed one or two steps and looked like a
    jump. Now its clock starts with the first mixed frame and moves on by at
    most 60 ms per frame, the fade is 600 ms, the blend does all three
    channels at once and skips the invisible corners. The log shows how many
    steps each fade had.
    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
    [main.cpp]
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2026-10-02 M 50 Spin, sharper pictures, phone videos in Firefox, crop reset; drop the driving design
    - M 50 Spin: a new mode, the M 50 badge with its quarters rotating (spin
    speed slider, motion boost). Only the small disc is redrawn per frame.
    - Phone videos (HEVC) always go through the page's own decoder: Firefox
    on Android plays them in hardware and hands back black frames for
    10-bit / HDR video, which uploaded as a black animation. Other videos
    are checked for all-black frames and the page says so.
    - Pictures: big photos are halved step by step before the final resize
    (one big step came out jagged), and the RGB565 conversion is dithered.
    - Fit to the display: a 'Reset zoom and position' b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
    [main.cpp, renderer.cpp, settings.h]
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2026-10-05 Android Auto app: the emblem's designs on the car's screen
    android/ is an Android Auto IoT app (Car App Library): a grid of the
    built-in designs (icons drawn by the emblem's renderer) and the filled
    picture slots (with their thumbnails); tap one to show it, Next for the
    next design, and a brightness picker. It finds the emblem on the phone's
    hotspot by itself (or 192.168.4.1) and uses the web page's requests. The
    phone screen shows whether the emblem was found and how to turn on
    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
    [automotive_app_desc.xml]
2026-10-05 Android Auto app 1.2: layout clear of the system bars, sturdier search
    - The phone screen drew under the title and status bars on Android 15
    (edge to edge), cutting off the top; it now has no title bar and keeps
    clear of the system bars.
    - Requests are only steered onto a Wi-Fi network (mobile data can use
    10.x addresses too, which could send hotspot requests the wrong way).
    - Also looks the emblem up by its mDNS name, and the phone screen says
    which addresses it searched when it can't find it.
    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
    [Emblem.kt]
2026-10-05 Android Auto app 2.0: a media app instead of a template app
    Android Auto 17.7 knew about the template (Car App Library) app but never
    put it in the launcher, as reported for other sideloaded template apps,
    while sideloaded media apps (VLC on the same phone) are listed. The app is
    now a media library: Designs and My pictures tabs as grids of tiles
    (design icons and slot thumbnails served by a content provider);
    playing a tile shows it on the emblem, next steps to the next design,
    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
    [automotive_app_desc.xml]
2026-10-08 Add G30 trunk hardware and build guide; warn about auto-off on always-on fuses
    - hardware/: print-ready 3MF and STL files (housing, tab cap, back plate with
    pegs or center hole, trunk-lid tray), OpenSCAD sources, VHB cutting template
    - docs/: build guide PDF, wiring diagram, print and install notes
    - Control page: Power tab now says to leave auto-off on Never unless a kill
    switch is fitted, shows a warning when a timer is picked, and the same for
    Car show time limits
    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
    [G30_emblem_display_SLIM_BACK_PLATE.3mf, G30_emblem_display_SLIM_BACK_PLATE_CENTER_HOLE.3mf, G30_emblem_display_SLIM_BACK_PLATE_CENTER_HOLE.stl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]
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2026-10-08 Kit edition firmware and hidden factory reset
    - KIT_DEFAULTS build flag and esp32-s3-kit env: INA219 + 12.2 V battery protection on from first start
    - Factory reset (/api/factoryReset): defaults, pictures erased, first-time Wi-Fi with a new temporary
    password; battery and level calibrations kept. Tucked away: hold BOOT for 10 s, or tap the
    Firmware heading on the Settings tab 7 times to show the button
    - CI builds and publishes both editions; kit edition installs from an unlisted kit.html
    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
    [main.cpp, settings.h]
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2026-10-09 Heat record: hottest temperature seen and time spent dimmed / dark
    Kept in flash (saved at most every 10 min and before sleeping): all-time
    hottest chip temperature and when, hottest since start-up, and total minutes
    the heat guard dimmed or blanked the screen. Shown on the Power tab with a
    Reset link (POST /api/heatReset); cleared by a factory reset.
    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
    [main.cpp]
2026-10-09 Switch to the YRDZXG 12/24 V -> 5 V 5 A converter
    Tray widened to 118 x 46 mm with a 61 x 32 mm pocket for the converter's base
    and mounting ears; STL, 3MF, source and preview updated. Guide parts list and
    print-and-install notes name the new converter (same red/black in,
    yellow/black out wiring).
    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
    [trunk_electronics_tray.3mf, trunk_electronics_tray.scad]
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2026-10-10 88 mm housing that loads from the back, centre-hole wiring, heat spreader
    - New housing (Halo_88_HOUSING): 88 mm over the 84 mm badge holder, centred 3" lens
    flush in a 1.5 mm pocket, display loads from the back into a wider board pocket and
    stops on a front lip, top covers the cable tab and ribbon (no tab cap), 45 deg bevel
    on the bottom edge, looser fit at the glass and cable tab.
    - Back plates: drop into the base on the brass studs, 14 mm centre hole, 4 x 6 mm
    locating pegs, dome for the dip in the badge seat; SPREADER version with a window
    and recess for a 50 mm aluminium disc and thermal pads.
    - Generator: hardware/source/halo_housing.py replaces the old housing .scad.
    - Tape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
    [G30_emblem_display_SLIM_BACK_PLATE.3mf, G30_emblem_display_SLIM_BACK_PLATE_CENTER_HOLE.3mf, G30_emblem_display_SLIM_BACK_PLATE_CENTER_HOLE.stl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]
